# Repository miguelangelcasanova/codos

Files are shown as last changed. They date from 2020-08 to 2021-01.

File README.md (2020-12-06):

# 💪CODOS💪

## Un sistema de bajo coste basado en ESP8266/ESP32 para la detección del CO<sub>2</sub> y otras variables ambientales para monitorizar la calidad del aire en el aula (o en otros lugares de trabajo)

*(Se trata de un proyecto en constante actualización y este documento está en constante redacción)*

*"Algunos científicos comentan que mejorar la ventilación y la calidad del aire es un método que las escuelas pueden usar para reducir el riesgo de transmisión del coronavirus.
Sin embargo, en una encuesta entre distritos escolares grandes del Norte de Texas, The Dallas Morning News encontró que las escuelas están lejos de alcanzar los parámetros de calidad del aire propuestos en junio por expertos en construcción.
Investigadores de la Universidad de Harvard recomendaron instalar filtros de aire de alta graduación, limpiadores de aire portátiles y fuentes de luz ultravioleta dentro de los conductos de aire para eliminar al virus.
Al revisar el nivel de dióxido de carbono en las aulas se puede comprobar si está entrando suficiente aire fresco..."*

Fuente: https://noticiasenlafrontera.net/escuelas-no-siguen-recomendaciones-de-calidad-del-aire-parar-reducir-exposicion-a-covid-19/

Otro artículo con información al respecto, (gracias Lina por el enlace):

https://www.caloryfrio.com/construccion-sostenible/ventilacion-y-calidad-aire-interior/colegios-coronavirus-calidad-aire-interior-ventilacion-adecuada-covid-19.html

Existen además evidencias de que los altos niveles de CO<sub>2</sub> influyen sobre el rendimiento de los alumnos en el aula.
https://pubmed.ncbi.nlm.nih.gov/25117890/

Artículos cómo estos y otros me han llevado a elaborar un pequeño dispositivo de bajo coste que permita monitorizar los niveles de CO<sub>2</sub> en las aulas con el objeto de poder medir la concentración de dicho gas y de esta forma saber cuándo tenemos que renovar el aire de un aula para poder seguir de la mejor forma posible las propias indicaciones al respecto de las administraciones públicas españolas:

https://www.miteco.gob.es/es/ministerio/medidas-covid19/sistemas-climatizacion-ventilacion/default.aspx

Si quieres saber más no dejes de leer este interesantísimo hilo en twitter: https://twitter.com/PabloFuente/status/1297457593368088576

Utilizando una hoja de cálculo podemos calcular la cantidad de CO<sub>2</sub>  en función de diversas variables del aula. En el siguiente artículo tenemos una calculadora que permite hacer dicho cálculo, (gracias Mercedes por el enlace):

https://medium.com/@jjose_19945/how-to-quantify-the-ventilation-rate-of-an-indoor-space-using-a-cheap-co2-monitor-4d8b6d4dab44

Este enlace https://schools.forhealth.org/ventilation-guide/ nos dice también cómo y cuánto debemos ventilar...

En este reciente informe del 03/11/2020 nos hablan con datos de la importancia de la ventilación y de la necesidad de ventilar en las aulas más allá de lo que indican muchos de los protocolos vigentes en muchas comunidades autónomas:   *El muestreo de mediciones realizado en centros educativos por el Comité de Expertos en Ventilación del COGITI, confirma la necesidad de contar con medidores de CO2:* 
https://cogiti.es/el-muestreo-de-mediciones-realizado-en-centros-educativos-por-el-comite-de-expertos-en-ventilacion-del-cogiti-confirman-la-necesidad-de-contar-con-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

## ¿Qué es 💪CODOS💪?

💪CODOS💪 es un pequeño circuito electrónico construido sobre un microcontrolador ESP32, un microcontrolador similar a un Arduino pero que ofrece conectividad WiFi y Bluetooth, aunque también hay otros Arduinos como el MKR1000 WiFi que te podrían servir.

Esto significa que podemos usar dispositivos de [Internet de las Cosas, (IoT)](https://es.wikipedia.org/wiki/Internet_de_las_cosas) que nos permiten monitorizar los datos de los sensores conectados a los mismos a través de Internet.

CODOS está pensado para medir la cantidad de CO<sub>2</sub> y otros parámetros ambientales para recomendarnos cuando deberíamos renovar el aire de un aula u otro espacio de trabajo, sobre todo cuando no se disponga de un sistema de ventilación forzada, o bien no sea posible mantener las ventanas abiertas todo el tiempo.

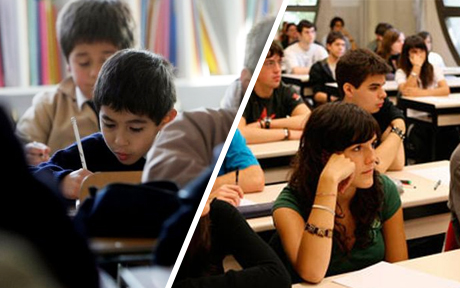
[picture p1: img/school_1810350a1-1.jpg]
CODOS es un guiño a hincar los codos en el aula...


Pupils at Henrietta Barnett School in Hampstead Garden Suburb raise their arms during a Key Stage Three maths lesson, the school received high scores during their Key Stage Three results, Wednesday 27 February, 2008. Photo: Jane Mingay

*CODOS (aka CO<sub>2</sub>) es un guiño a hincar los "CO<sub>2</sub>" en el aula... ;)*

* Con un simple Arduino, un sensor de CO<sub>2</sub> y unos led podemos construir un sistema simplificado que permita indicar cuando los niveles de CO<sub>2</sub> están dentro de unos determinado umbrales, esa fue mi primera idea y publicaré también esta versión; pero cambiando el Arduino por un ESP8266 o un ESP32 podemos además enviar los datos a un servidor y monitorizar por ejemplo los datos de distintas aulas de forma centralizada, almacenar datos estadísticos en una base de datos o realizar otras muchas tareas que podrían sernos útiles sin incrementar prácticamente el coste del dispositivo.

### BOM (Bill of materials) / Lista de materiales
En su versión IoT, para construir CODOS se necesitan los siguientes elementos:
- Un ESP32 por ejemplo el ESP32-DOIT-DEVKIT (también puedes utilizar un ESP8266)

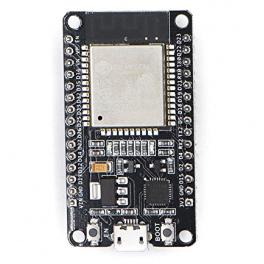
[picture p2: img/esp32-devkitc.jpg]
ESP32-DEVKITC


- Un sensor de CO<sub>2</sub>, como el MH-Z19b. Su gran ventaja es que se trata de un sensor NDIR por lo que mide directamente CO<sub>2</sub>.  (he probado también con otros sensores como el Sensirion SDC30 pero su coste es mucho más elevado). 

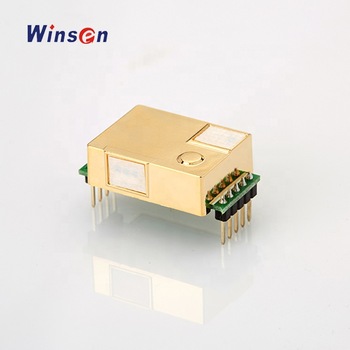
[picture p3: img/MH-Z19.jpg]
Sensor CO2 MH-Z19

 
- Otra alternativa más barata es el sensor de eCO<sub>2</sub> CCS811. Este sensor no mide directamente CO<sub>2</sub>, sino una estimación a partir de la presencia de otros gases. Aunque es útil para medir calidad del aire, no es el sensor más adecuado para este proyecto ya que puede dar niveles muy altos por otros motivos, y no solamente por acumulación de CO<sub>2</sub>.

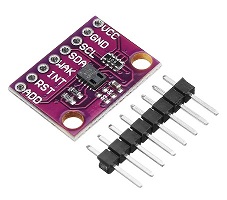
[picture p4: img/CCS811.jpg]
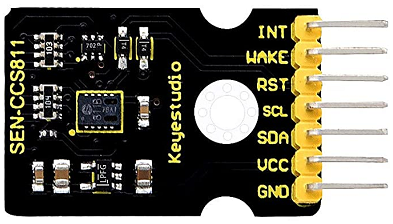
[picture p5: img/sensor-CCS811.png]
Sensor CO2 CCS811
 

- Opcionalmente un sensor de humedad, presión y temperatura BME280

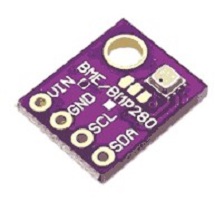
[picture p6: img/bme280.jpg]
Sensor BME280


- Opcionalmente leds de varios colores por ejemplo rojo, naranja y verde para construir un "semáforo" que indique los niveles de CO<sub>2</sub> o directamente utilizar un módulo de semáfot

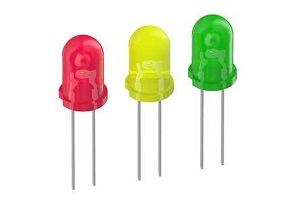
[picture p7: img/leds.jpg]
Diodos led
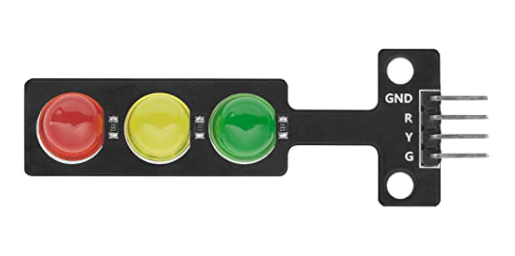
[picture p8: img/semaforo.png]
Semáforo de diodos LED
 

- Opcionalmente una pantalla OLED SSD1306 u otra (o un ESP32 que la incluya)

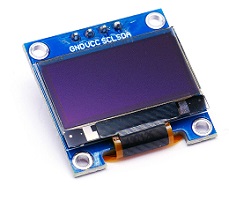
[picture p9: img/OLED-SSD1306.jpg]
OLED SSD1306


- Necesitarás además cables dupont para conectar entre sí los distintos elementos.

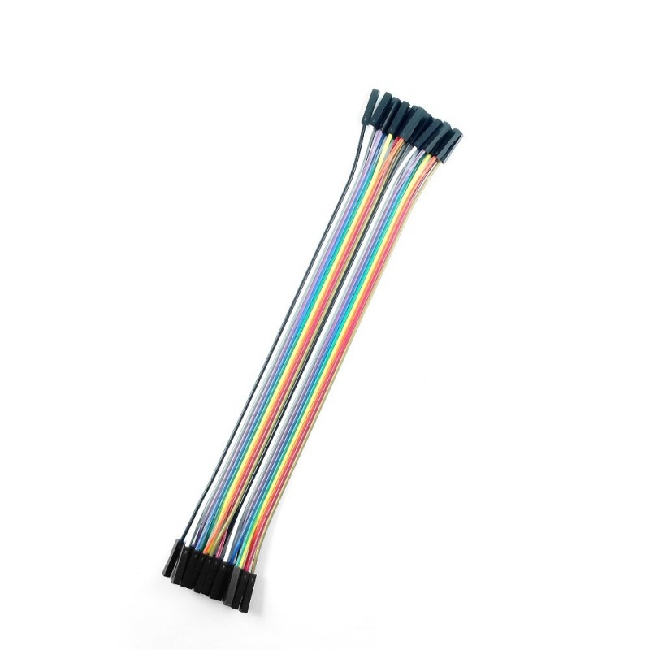
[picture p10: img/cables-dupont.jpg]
Cables Dupont


- Para alimentar el dispositivo podrás utilizar el puerto USB de un ordenador o mejor un cargador de móvil con conexión microUSB para los ESP o el que corresponga para el Arduino

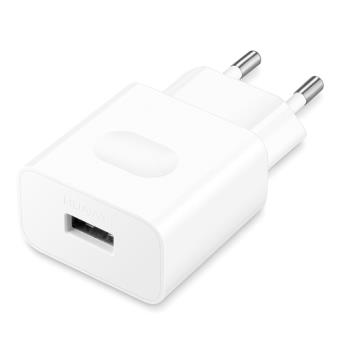
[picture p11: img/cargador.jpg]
Cargador de móvil
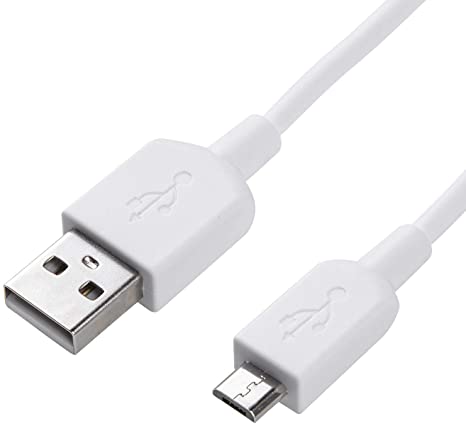
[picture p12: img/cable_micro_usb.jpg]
Cable Micro-USB


## Montaje

### Versión Arduino

Vamos a exponer primero de forma sencilla cómo se conecta el sensor de CO<sub>2</sub> CCS811 a un Arduino Nano o UNO, esta versión es la más económica y sencilla del dispositivo. Simplemente hemos de utilizar 5 cables Dupont hembra-hembra o macho-hembra respectivamente y unir los siguientes pines del sensor a otros tantos pines del Arduino:

- **Vcc** con un cable rojo lo uniremos al pin de 3.3V del Arduino
- **GND** con un cable negro lo uniremos a uno de los pines GND del Arduino
- **SDA** se conecta al pin A4 del Arduino
- **SCL** se conecta al pin A5 del Arduino
- **Wake** o **AWake** se conecta al otro pin GND del Arduino, aunque también podría controlarse con pin de salida.

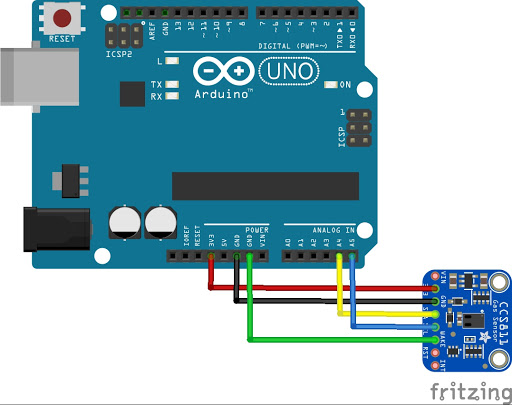
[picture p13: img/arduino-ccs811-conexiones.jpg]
Conexión del sensor CCS811 al Arduino


*Conexión del sensor CCS811 a un Arduino UNO*

Luego simplemente hemos de conectar un cable USB y podremos programar el Arduino con el código necesario para poder leer los datos del sensor.

Puedes utilizar el código de la carpeta dev/plotter para monitorizar los valores del CO<sub>2</sub> y la TVOC gráficamente. Puedes acceder al mismo en el siguiente enlace: https://github.com/miguelangelcasanova/codos/blob/master/dev/arduino/plotter/plotter.ino

El código está completamente comentado por lo que si lo deseas no debería resultarte muy dificil poder adaptarlo a tus necesidades.

En esta versión del dispositivo los datos sólo pueden monitorizarse a través de un ordenador conectado mediante dicho cable USB, por eso en la versión definitiva utilizaremos un ESP8266 o un ESP32 que funcionan de forma similar pero permiten además enviar los datos vía WiFi y en el caso del ESP32 también vía Bluetooth.

Descarga el archivo, envía el firmware al Arduino y abre el monitor serie o mejor el plotter serie y podrás visualizar los valores del sensor:

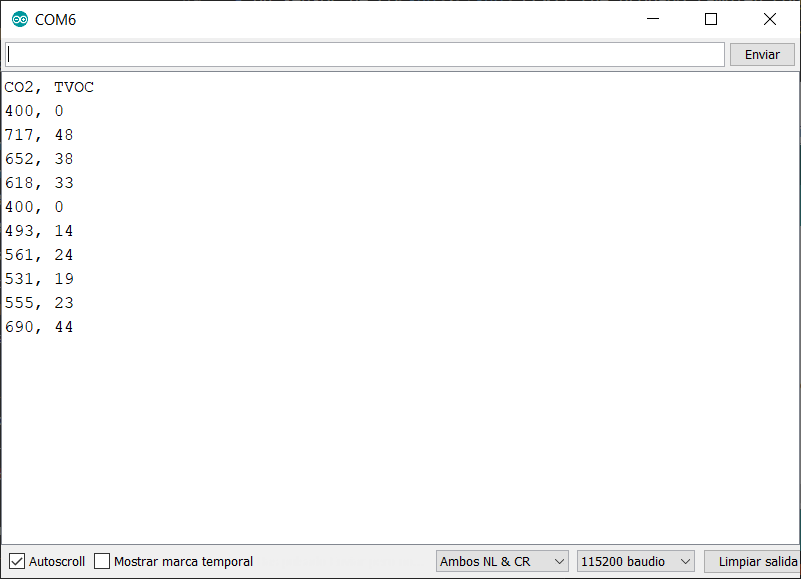
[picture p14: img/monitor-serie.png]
Monitor serie del IDE de Arduino con los valores medidos del sensor


*Monitor serie del IDE de Arduino*

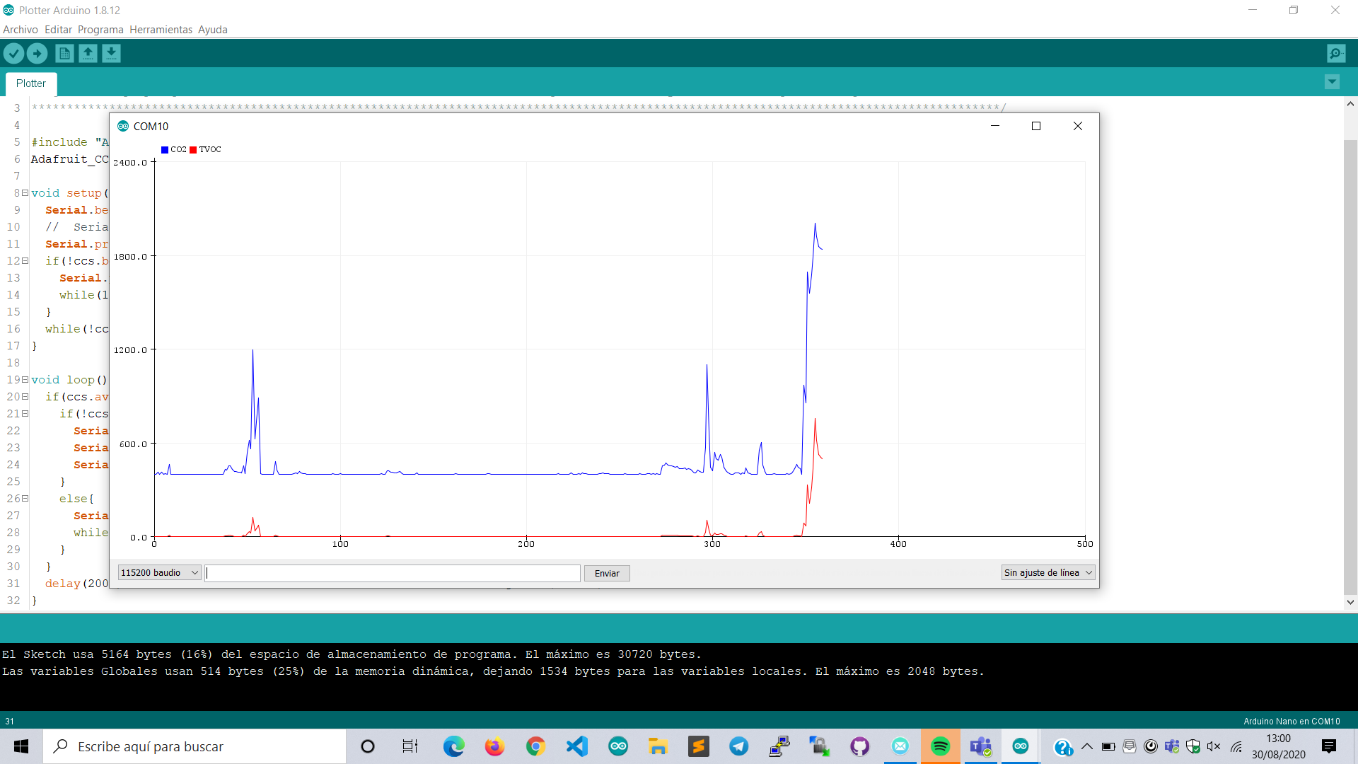
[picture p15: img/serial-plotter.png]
Serial Plotter del IDE de Arduino con los valores medidos del sensor


*Serial Plotter del IDE de Arduino*

### Version ESP8266 / ESP32

La conexión de los sensores es muy similar a la que hemos descrito para el arduino y es también muy sencilla, tanto el sensor de CO<sub>2</sub> como el sensor ambiental utilizados utilizan conexiones i2c, es decir basta con alimentarlos a 3.3V y masa. Luego hay que conectar a los **GPIO22** y **GPIO21** que en el ESP32 corresponden a las conexiones SCL y SDA del mencionado protocolo respectivamente o a los pines **D2** y **D1** que corresponden igualmente a SDA y SCL para el ESP8266.

Si deseas conectar la pantalla OLED o el sensor ambiental BME280, se conectan también en estos mismos pines en ambos casos.

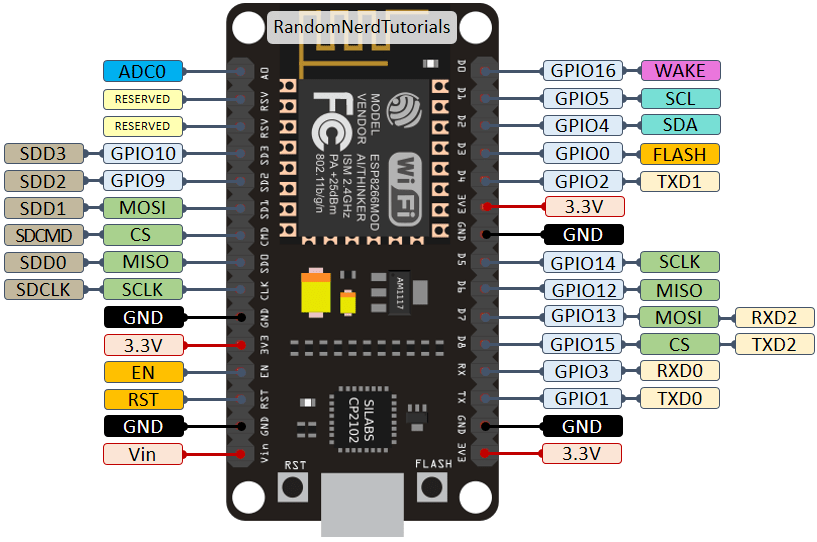
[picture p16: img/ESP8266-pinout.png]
Pinout del ESP8266

*Pinout del ESP8266*

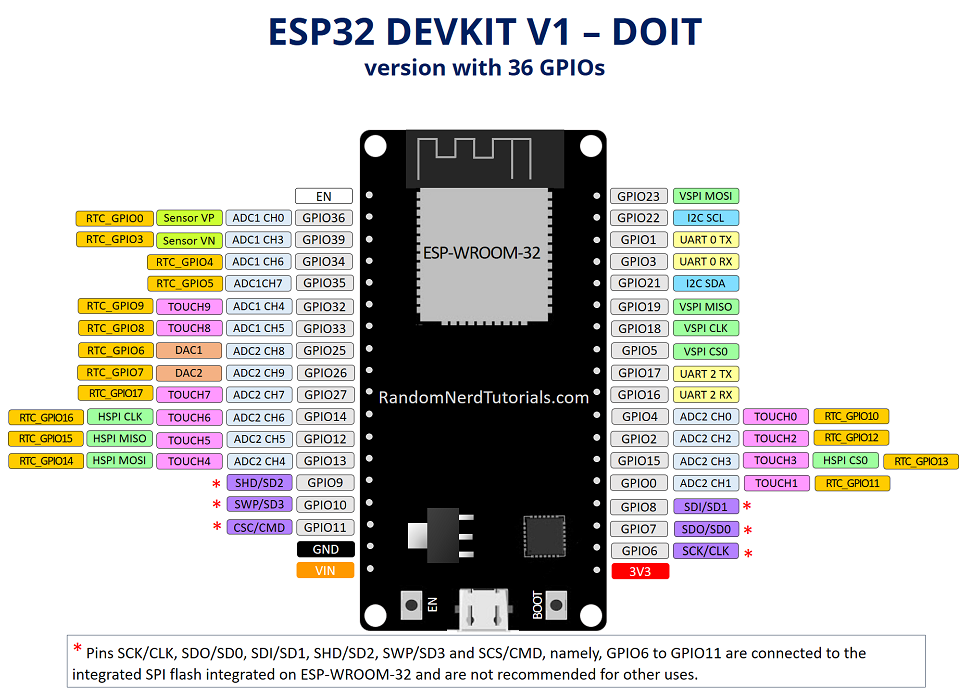
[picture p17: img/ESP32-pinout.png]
Pinout del ESP32

*Pinout del ESP32*

Dado que podemos utilizar dos pines para conectar varios sensores o la pantalla necesitaremos utilizar una placa de prototipos o diseñar una placa de circuito impreso para conectarlos todos en el mismo punto.

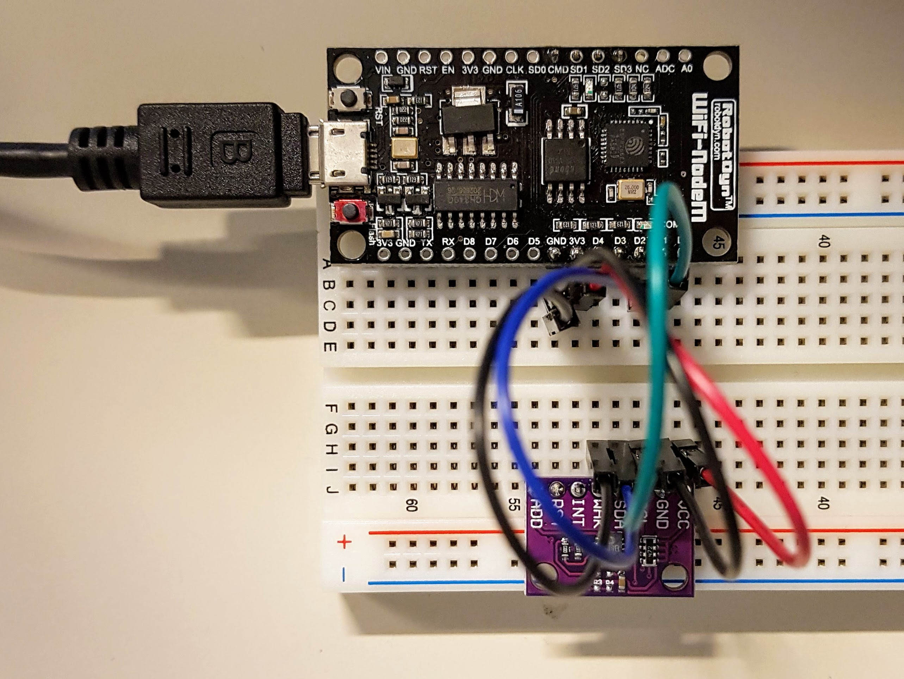
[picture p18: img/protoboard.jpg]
Conexión del sensor CCS811 con una placa protoboard
 *Conexión del sensor CCS811 a un ESP con una placa protoboard*

Para la conexión de los diodos led al tratarse de salidas de 3.3V deberíamos utilizar resistencias limitadoras de corriente y conectarlos a través de estas a cualquiera de los GPIO, yo he escogido los GPIO9, 10 y 11. Al conectar los diodos led hemos de tener en cuenta su polaridad.

### Otras versiones
Gracias a otros miembros de la comunidad el proyecto ha ido creciendo y enriqueciéndose con las contribuciones de makers, makerspaces y fablabs.

En la carpeta esp32 hay a tu disposición una versión avanzada que incluye el uso de bases de datos como InfluxDB para almacenar y visualizar en el futuro los datos de muchos sensores creada por Andreas del Makespace Mallorca.

### El programa
También he diseñado varias versiones del programa según la plataforma utilizada.
El programa debe cargarse desde el entorno IDE de Arduino o desde VS Studio Code (Platformio) en la placa correspondiente.

### El dispositivo
He diseñado una caja imprimible en 3D para poder albergar el dispositivo aunque este puede montarse directamente sobre una placa de prototipos si no se tiene la habilidad para soldar unos cuantos componentes aunque su montaje debería resultar especialmente sencillo.

En la carpeta STL hay diseños de cajas imprimibles en 3D y en Thingiverse puedes encontrar también otros modelos.

### Usando el dispositivo
El dispositivo se conecta automáticamente a la red del aula para permitir que los datos de los sensores pueden visualizarse en una página web que genera el dispositivo desde cualquier otro dispositivo conectado a la misma red. Para ello debes averiguar la dirección IP del dispositivo y abrir en tu navegador una URL del tipo siguiente: http://192.168.1.105 dónde los números indican la dirección IP local del dispositivo en la red local.

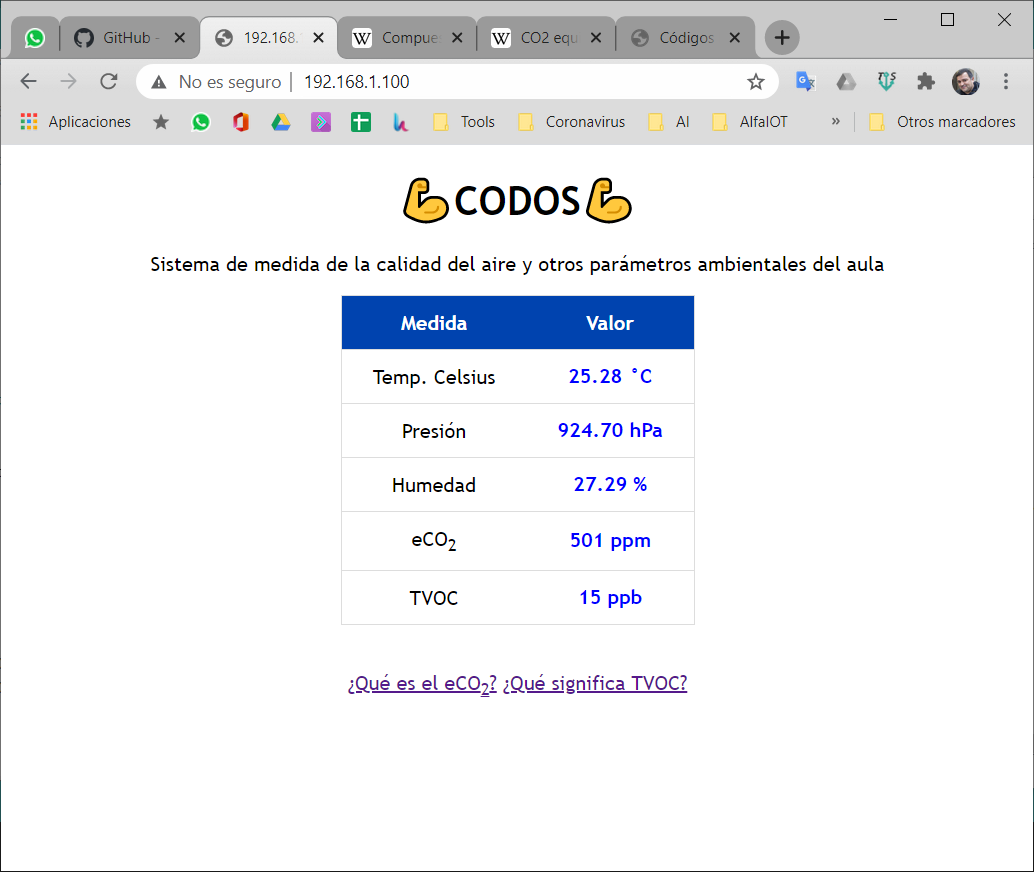
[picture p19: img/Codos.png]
CODOS


*Pantalla de datos de las primeras versiones de CODOS*

### Información para el calibrado de los sensores
Documentación para estudiar el comportamiento de los sensores en aire bajo condiciones controladas mediante materiales caseros.
[PROCEDIMIENTO](/doc/C%C3%A1lculos%20de%20concentraci%C3%B3n%20de%20CO2.pdf)

### To do
En un proyecto como este hay muchas cosas que siempre quedan por hacer. Por ejemplo, la calibración de los sensores es fundamental y no está bien probada, también es necesario hacer pruebas de campo montando sensores en las aulas y tomando medidas para comprobar su fiabilidad.
Si quieres colaborar no tienes más que ponerte en contacto con el grupo de trabajo por Telegram: https://t.me/codos_ventilacion (a 31 de octubre en el grupo hay 150 personas).

### Preguntas frecuentes

#### ¿Cuál es el objetivo del proyecto?
Dotar a las aulas y otros espacios de trabajo de una forma sencilla y económica
de medir la calidad del aire, en concreto de la concentración de CO<sub>2</sub>

#### ¿Dónde comprar los componentes?

El ESP32 y los leds se pueden comprar en muchas tiendas físicas de electrónica en España o a través de Internet. En China por supuesto resultan mucho más económico; pero tardarás en tenerlo varias semanas en tener los componentes en tus manos.
Los sensores son un poco más difíciles de localizar en tiendas físicas pero puedes adquirirlos igualmente en China o un poco más caros encontrarlos a través de ebay o Amazon.

El ESP32 lo puedes comprar en España por unos 10€ por ejemplo en:

https://www.ebay.es/itm/EL0116-ESP-WROOM-32-ESPRESSIF-Placa-Desarrollo-Arduino-WiFi-Bluetooth-Dual-Core/233565682462

En la misma tienda puedes comprar los LEDs y unos cables Dupont hembra-hembra.

En ebay y en Amazon hay muchas tiendas que te ofrecen el sensor de CO2 o el de humedad y temperatura pero su coste es mucho más elevado que pidiéndolo a China:

https://www.ebay.es/itm/CCS811-Carbon-Monoxide-CO-VOCs-Air-Quality-Numerical-Gas-Sensors-CJMCU-811/323688562130

https://www.amazon.es/TECNOIOT-Monoxide-Quality-Numerical-CJMCU-811/dp/B07RGLMS1J

Este es otro modelo que resulta también muy económico:

https://www.amazon.es/KEYESTUDIO-Quality-Arduino-Monoxide-Numeric/dp/B086HCSM6N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

Comprando 5 unidades del ESP32 te salen a 6€ en el siguiente enlace:

https://www.amazon.es/gp/product/B074RG86SR

En Aliexpress últimamente están entregando en 10 días (Hoy es 29/08/2020)

https://es.aliexpress.com/item/32903358923.html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,searchweb201602_,searchweb201603_

El MH-Z19b lo puedes adquirir también en Amazon o Aliexpress por unos 16-25€:
https://es.aliexpress.com/item/32946106807.html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

#### Otros proyectos parecidos

- *Air quality sensor:* This simple, fancy looking, ESP8266 based sensor measures values of CO2 and TVOC air pollutants. As output there is addressable RGB led strip, and/or optional OLED display which can show real time levels. https://github.com/Luc3as/Air-quality-Sensor/ (en inglés)

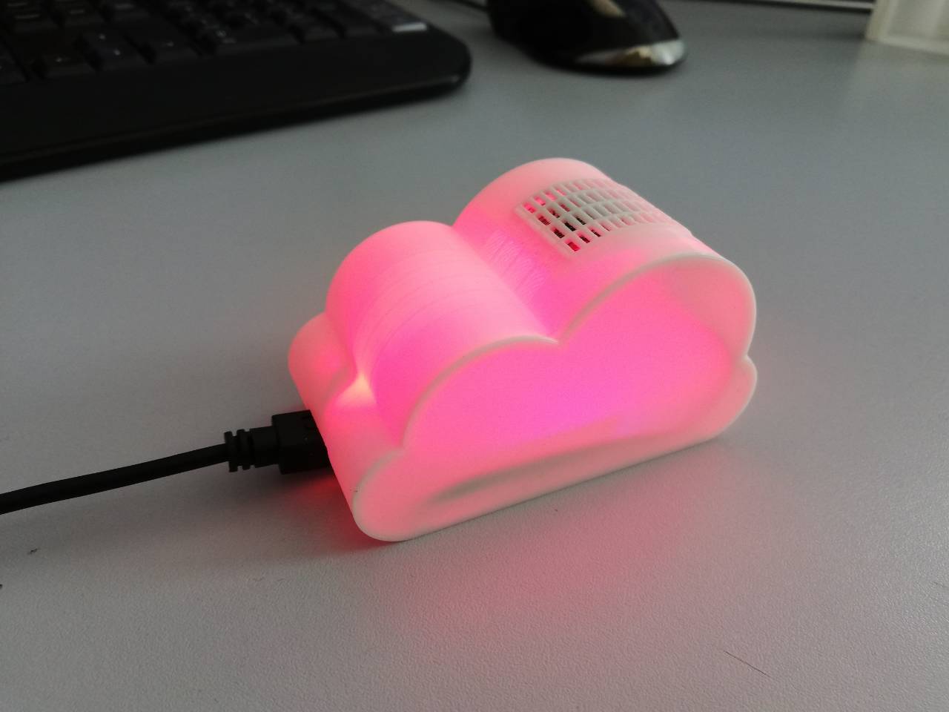
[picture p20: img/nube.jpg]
   
   
- *CO2 Cuckoo Clock for schools and businesses (Why not eCO2?)* del maker y youtuber suizo Andreas Spiess:  https://www.youtube.com/watch?v=hcPdZlpaRTo (en inglés)
  
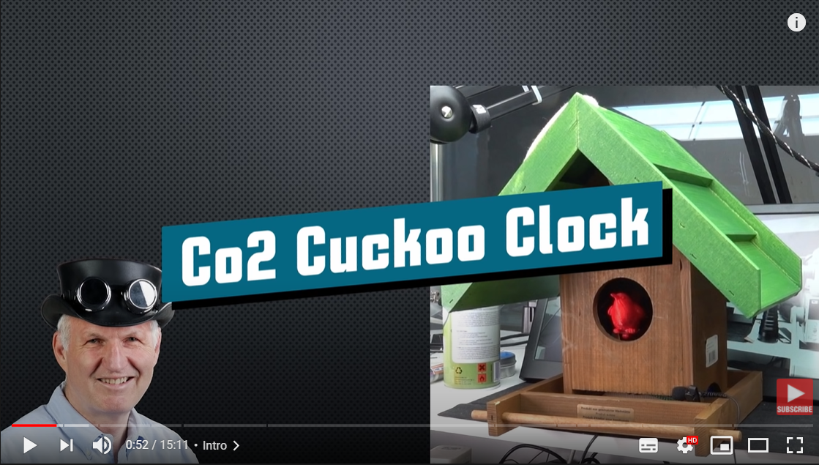
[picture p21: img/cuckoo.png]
  
  
- *Air quality meter:* http://www.futurashop.it/breakout-CCS811-air-quality-ft1331m-qualit%C3%A0%20aria?search=ccs811 (en italiano) 
  La caja puedes descargarla d*Air quality meter* (de David Daghetta, en Thingiverse): https://www.thingiverse.com/thing:2569792 (en Inglés)

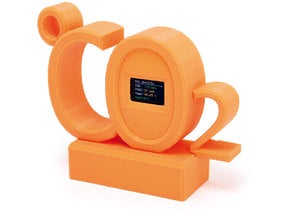
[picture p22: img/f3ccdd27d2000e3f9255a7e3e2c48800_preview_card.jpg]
CO2


*(Este documento está en constante redacción)*

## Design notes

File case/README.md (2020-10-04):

# 3D printable housings for CODOS air quality sensor based on ESP32/8266s & Arduinos
Housings with lot of space to hold several sensors and due to an interchangable base adaptable to all kinds of development board form factors. 
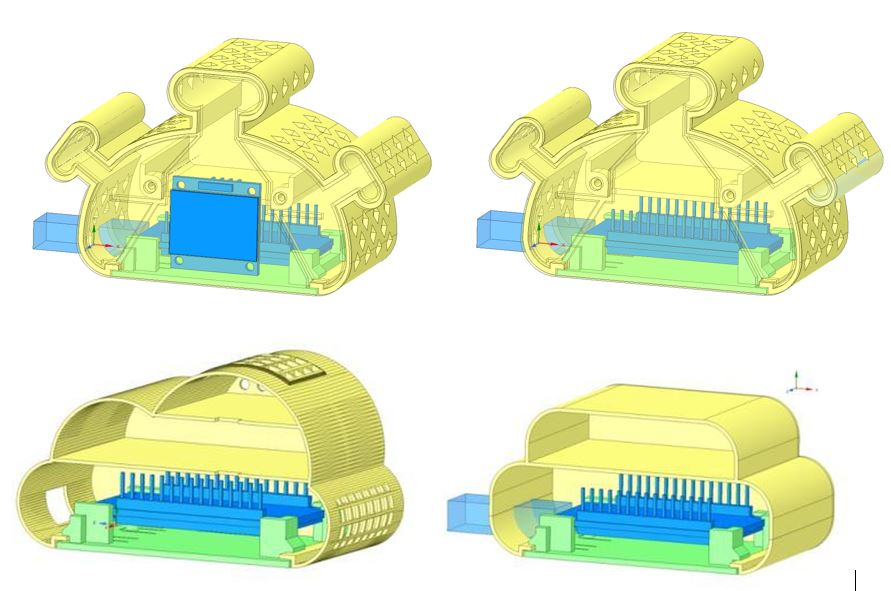
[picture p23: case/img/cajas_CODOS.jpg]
Screenshots housings


## Variety of holding bases:
* ESP32 30 pin, 51,5 x 28,5 mm
* ESP32 38 pin, 58 x 28 mm
* ESP8266 30 pin (NodeMCU), 58 x 31,2 mm
* ESP32-CAM, 40 x 27 mm
* TTGO T1 38 pin, 53,8 x 26,9 mm
* NANO 30 pin, 43,7 x 18 mm
* Wemos D1 mini, 34,2 x 25,4 mm - credits to Luc3as https://github.com/Luc3as/Air-quality-Sensor - based his design on https://www.thingiverse.com/thing:2997734
* UNO, 68,8 x 53 mm - Attention: needs housing "bicho_100_para_UNO"

## Different shapes
* "Virus" shaped
* "Cloud" shaped - credits to Luc3as https://github.com/Luc3as/Air-quality-Sensor - based on his design on https://www.thingiverse.com/thing:2997734 
* to come: Rectangular with rounded corners

## Versions
* v0.7 added case & base for UNO, reduced wall thickness
* v0.6 correction "bicho", base Wemos D1 mini added, "cloud" added
* v0.5 correction base TTGO T1, added premarked holes for LEDs
* v0.4 added version for 0.96" OLED + two more bases (TTGO T1 + NANO)
* v0.3 added side holes on top tentacle for better breathing of MH-Z19P sensor
* v0.2 initial release

# License
<br /><span xmlns:dct="http://purl.org/dc/terms/" href="http://purl.org/dc/dcmitype/Text" property="dct:title" rel="dct:type">CODOS case "bicho"</span> by <span xmlns:cc="http://creativecommons.org/ns#" property="cc:attributionName">@Andreas_IBZ (Telegram)</span> is licensed under a <a rel="license" href="http://creativecommons.org/licenses/by-nc-sa/4.0/">Creative Commons Attribution-NonCommercial-ShareAlike 4.0 International License</a>.

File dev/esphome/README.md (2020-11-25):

# Distintos sketches para ESPHome.

### nodemcu_ccs811.yaml

Archivo simple, para nodemcu y un sensor ccs811. 
Es necesario editarlo para configurar las credenciales de WiFi y la dirección del servidor MQTT

### esp32_mhz19_display.yaml

Plantilla para ESP32 con sensor MH-Z19 y display oled. Este archivo depende de otros incluidos en ./co2_common.
Es fácil modificar el tipo de sensor utilizado simplemente comentando/descomentando las líneas correspondientes:

    packages:
      display: !include "co2_common/display.yaml"
      mqtt: !include co2_common/mqtt.yaml 
      mhz19: !include "co2_common/sensor_mhz19.yaml"
      bme280: !include "co2_common/sensor_bme280.yaml"
      #  mq135: !include "co2_common/sensor_mq135.yaml"
      #  ccs811: !include "co2_common/sensor_ccs811.yaml"
 
Es necesario crear un archivo co2_common/secrets.yaml con las credenciales de wifi y otros parámetros. En esa carpeta se encuentra un archivo secrets.yaml.sample de ejemplo.

### wemosD1_ccs811_display.yaml
Mismo sistema de plantilla que el anterior, pero configurado para una placa WemosD1 y sensor CCS811

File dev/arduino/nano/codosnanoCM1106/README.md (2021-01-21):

# Arduino NANO + Display Oled + Sensor CM1106

Versión del proyecto codosnanoMHZ19, adaptada al sensor CM1106.

Soporta display OLED I2C conectado a A4 y A5

Semáforo de LEDS indicadores del estado de "alarma" (rojo, amarillo, verde), conectados a los pines 6, 7 y 8.

Se puede conectar un interruptor entre los pines 3 y GND. Al pulsarlo durante más de 2 segundos se calibra el sensor manualmente a 415ppm. (Esto debe hacerse al aire libre o en la ventana, después de tener el sensor funcionando varios minutos)

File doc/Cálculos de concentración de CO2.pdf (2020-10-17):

Determinación de ppm de CO2 en una garrafa de 5 litros de agua con aire limpio.

En el siguiente procedimiento se pretende obtener información sobre el calibrado de los sensores de concentración de CO2 en el aire para el proyecto CODOS, que busca monitorizar la concentración de CO2 en las aulas, como medida de la calidad del aire y optimizar la ventilación en la lucha contra el SARS-CoV-2.

https://github.com/miguelangelcasanova/codos

Pretendemos comparar del valor obtenido por el sensor y el valor teórico en aire bajo condiciones controladas.

A través de una reacción química buscamos modificar el valor de la concentración de CO2 en el aire contenido en la garrafa para conocer la respuesta de los diferentes sensores.

El aire de la garrafa debe ser obtenido en el exterior y alejado de fuentes de contaminación para considerar que partimos de una concentración de 400ppm de CO2.

La reacción tendrá lugar con la garrafa completamente cerrada.

Materiales:
- Una garrafa de agua (vacía) de 5 litros
- Bicarbonato sódico
- Vinagre
- Una jeringuilla que nos permita medir 1ml.

Consideraciones
- 1 mol de aire en CN ocupa 22,4 l
- Capacidad de la garrafa 5,1 l
- Proporción de ácido acético en el vinagre común 4%
- Reactivo limitante: Ácido acético, ya que es más fácil calcular su volumen
- Densidad del vinagre 1g/ml
- El contenido de CO2 en el aire limpio es de 400 ppm → 0,04%

Reacción química
NaHCO3 + CH3COOH => NaC2H3 O2 + H2O + CO2

Cada molécula de ácido acético produce una molécula de CO2.

Masa molecular (CH3COOH) = 60g/mol

Masa molecular (CO2) = 44g/mol

Masa molecular (NaHCO3) = 84g/mol

Aire de la garrafa inicial

1 mol ≈ 22,4 l por lo que tendremos aprox. 0,2277 moles ≈ 1,416·10²³ moléculas

Vinagre d≈1g/ml y → 1ml equivale a 1g de vinagre. En 1ml de vinagre tendremos 0,04g de CH3COOH

0,04g de CH3COOH son aprox. 4,015·10²⁰ moléculas

Después de la reacción
Nº total de moléculas en estado gaseoso = 1,416·1023 + 4,015·10²⁰ = 1,42 · 10²³ moléculas

Nº de moléculas de CO2 = 4,015·10²⁰ (obtenidas) + 4·10⁻⁴

- 1,416·10²³ = 4,5814 ·10²⁰ moléculas

Proporción
4,5664 ·10²⁰ / 1,42 · 10²³ ≈ 0,003226 ≈ 3226 ppm

Conclusión

Disolviendo completamente 1ml de vinagre en una cantidad suficiente de bicarbonato sódico (una cucharita pequeña) dentro de una garrafa llena de aire limpio (400 ppm de CO2) la concentración de CO2 ascenderá a 3226 ppm

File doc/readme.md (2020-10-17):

# Documentación

En esta carpeta hay diversos documentos útiles para el proyecto. Datasheet de diferentes sensores, guías de programación, información técnica y otra información de interés sobre el CO2.

A través del siguiente enlace se podrá tener acceso al documento en Google Docs de presentación del proyecto a centros educativos. Se encuentra abierto y es de libre edición.

[Documento Proyecto CODOS en Google Docs](https://docs.google.com/document/d/11AyAutbdyGciLlmV7_w-OJjZyPklUf59CmAjkQRwt4g)

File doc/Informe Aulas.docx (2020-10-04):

# Sistema de bajo coste basado en ESP8266/ESP32 para la detección del CO2 y otras variables ambientales para monitorizar la calidad del aire en el aula

"Algunos científicos comentan que mejorar la ventilación y la calidad del aire es un método que las escuelas pueden usar para reducir el riesgo de transmisión del coronavirus. Sin embargo, en una encuesta entre distritos escolares grandes del Norte de Texas, The Dallas Morning News encontró que las escuelas están lejos de alcanzar los parámetros de calidad del aire propuestos en junio por expertos en construcción.
Investigadores de la Universidad de Harvard recomendaron instalar filtros de aire de alta graduación, limpiadores de aire portátiles y fuentes de luz ultravioleta dentro de los conductos de aire para eliminar al virus. Al revisar el nivel de dióxido de carbono en las aulas se puede comprobar si está entrando suficiente aire fresco..."

Fuente: https://noticiasenlafrontera.net/escuelas-no-siguen-recomendaciones-de-calidad-del-aire-parar-reducir-exposicion-a-covid-19/

Miguel Ángel Casanova González, director del Centro Integrado de Formación Profesional Río Tormes de Salamanca, es el autor del proyecto CODOS que -en base a que diversos estudios e investigaciones prestigiosas, relacionan la cantidad de CO2 en las aulas con la capacidad de concentración del alumnado, así como de aumento de probabilidad de contagio de la COVID-19- pretende crear un dispositivo de bajo coste y con una precisión de medida suficientemente buena, como para poder detectar niveles nocivos de CO2 y por tanto, establecer cuándo se debe ventilar el aula.

Es obvio mencionar que hoy en día existe preocupación en el ámbito educativo debido a que las normas sanitarias recomiendan clases con pocos alumnos y siempre en entornos bien ventilados o exteriores. Estos escenarios no siempre se pueden conseguir en los centros educativos y crea la duda de cuándo se debe ventilar el aula. A finales del verano tal y como nos encontramos ahora, este no parece ser un riesgo inminente, ya que se pueden mantener las ventanas de las clases abiertas de forma permanente, pero en invierno y más en Salamanca de donde es Miguel Ángel, esto crea un serio problema. Es por ese motivo que Miguel Ángel decide ir un paso más allá, investigar cómo puede tratar el tema siempre usando el método científico y plantear una solución que sea posible técnicamente y viable a nivel económico.

Cabe decir que Miguel Ángel debido a su formación como físico, su inquietud por la innovación tecnológica y entusiasmo por compartir el conocimiento, ha creado el proyecto CODOS de forma abierta, lo que significa que cualquiera que quiera puede colaborar. Y es aquí en donde entra la comunidad maker de Mallorca con el Fablab Mallorca. Nos hemos puesto en contacto con él, hemos visto cuales son nuestras posibilidades para contribuir de nuevo con la sociedad a la hora de combatir contra la COVID-19 (ya lo hicimos hace unos meses creando 20.000 pantallas de acetato para nuestros enfermeros, médicos, etc…) y queremos ofrecer la posibilidad a cualquier escuela que lo crea útil, de montar dichos dispositivos a coste únicamente el de los materiales.

Para que las escuelas puedan tomar una decisión y conocer mejor en que consiste el proyecto CODOS, nos permitimos recoger la información que Miguel Ángel tiene colgada en su repositorio de Github (https://github.com/miguelangelcasanova/codos) y reproducirlo en este documento:

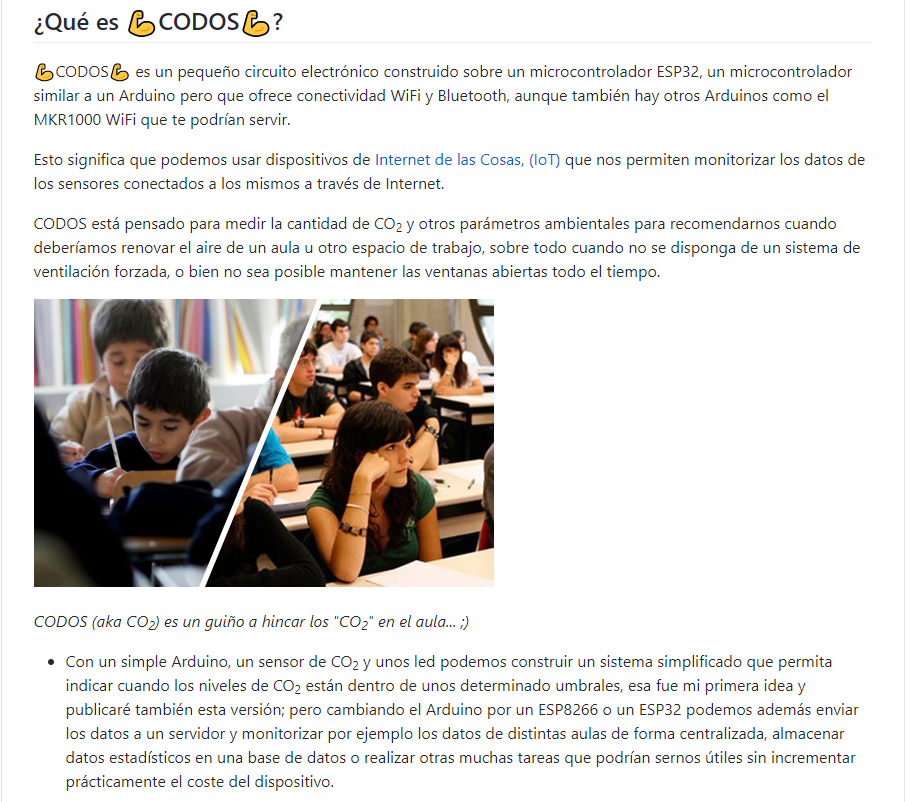
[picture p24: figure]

Fuente: https://github.com/miguelangelcasanova/codos

Sin entrar mucho en detalle, pero con el afán de procurar una visión global del dispositivo propuesto, se compone de un microcontrolador ESP32 con un sensor de CO2 CC811. Dicho sensor se encarga de medir cada cierto tiempo la cantidad de CO2 y la calidad del aire tVoc (Total Volatile Organic Compounds). Las principales características de este sensor son:

- Es capaz de medir el CO2 en un rango de 400ppm hasta 29206ppm
- Es capaz de medir el tVoC en un rango que va desde los 0ppb hasta 32768ppb
- Es capaz de medir la temperatura y humedad
- Funciona en un rango de temperaturas de -40ºC a 80ºC

Dicho dispositivo se encapsulará en una caja hecha mediante una impresora 3D que permitirá el flujo del aire correcto por el sensor y mostrará mediante los 3 leds (Rojo, Naranja y Verde) la calidad del aire medida.

Todos los detalles del proyecto, material, construcción y código, están accesible en el github de Miguel Ángel y de forma abierta a quien quiera usarlo para montarlo de forma autónoma. En nuestro caso, el Fablab Mallorca (http://fablabmallorca.com/), hemos decido ponerlo en marcha, crear varios dispositivos y presentarlos a las escuelas para que puedan ver su uso y efectividad.

Como ya hemos indicado anteriormente, el dispositivo cuenta con 3 leds a modo de semáforo que indica el nivel de concentración de CO2 en el aula, como también una web que publica el mismo dispositivo, accesible por wifi.

CODOS

Toda la información sobre el proyecto está disponible en el github (https://github.com/miguelangelcasanova/codos) y recomendamos su lectura, ya que es allí donde se publican las mejoras, cambios, preguntas, etc.

Finalmente, recomendamos también la lectura de los artículos que Miguel Ángel publica sobre los que basa su investigación y el porqué del proyecto.

Documento creado por Makespace Mallorca (https://makespacemallorca.org/) para la difusión del proyecto CODOS

Proyecto CODOS (https://github.com/Makespace-Mallorca/codos) en el github de Makespace Mallorca

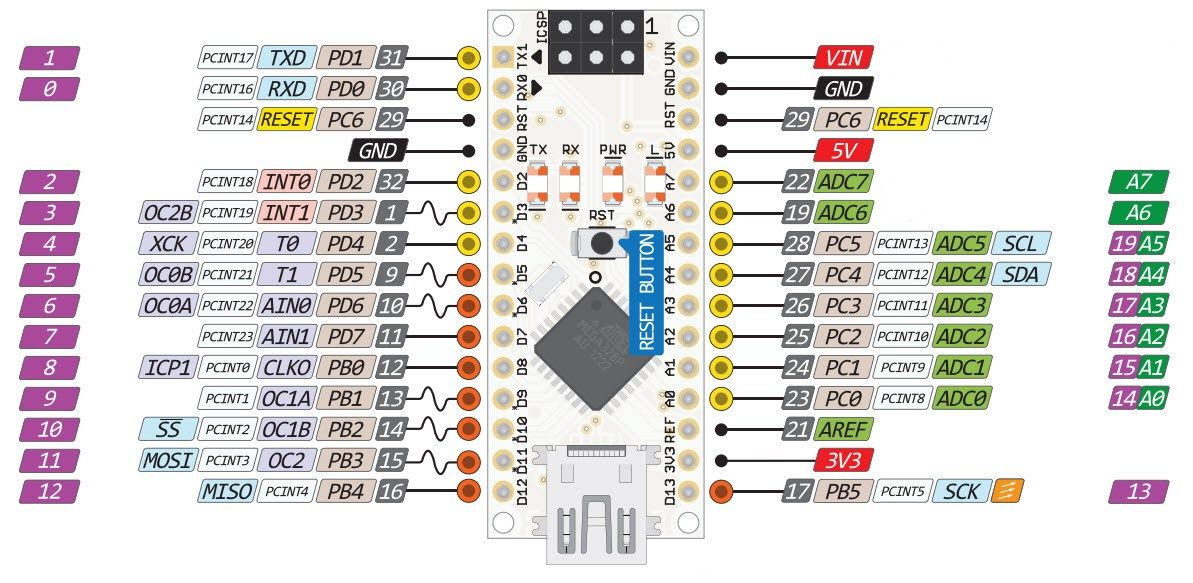
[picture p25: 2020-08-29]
img/arduino-nano-pinout.jpg

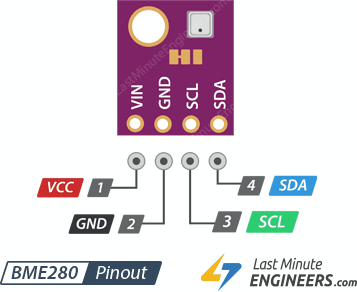
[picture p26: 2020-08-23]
img/BME280-Pinout-Temperature-Humidity-Barometric-Pressure-Sensor.png

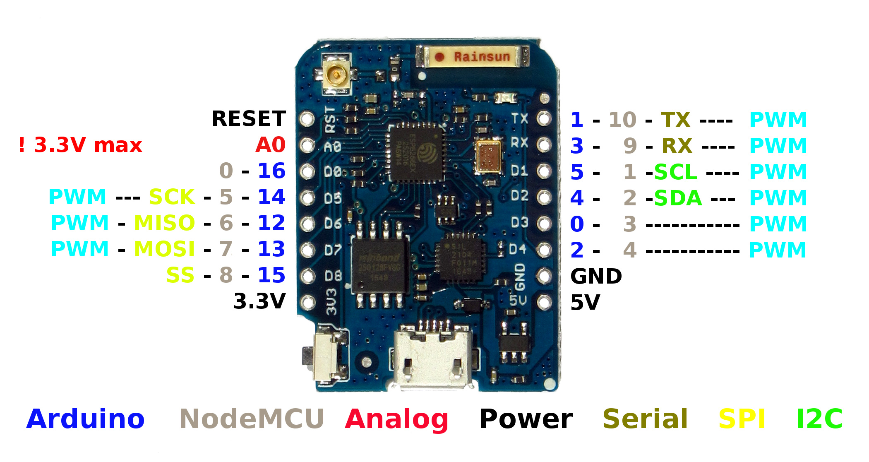
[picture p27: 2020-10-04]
dev/esp8266/codos_WeMos_D1_Mini_Pro/WEMOS D1 MINI Pro pinout.jpg

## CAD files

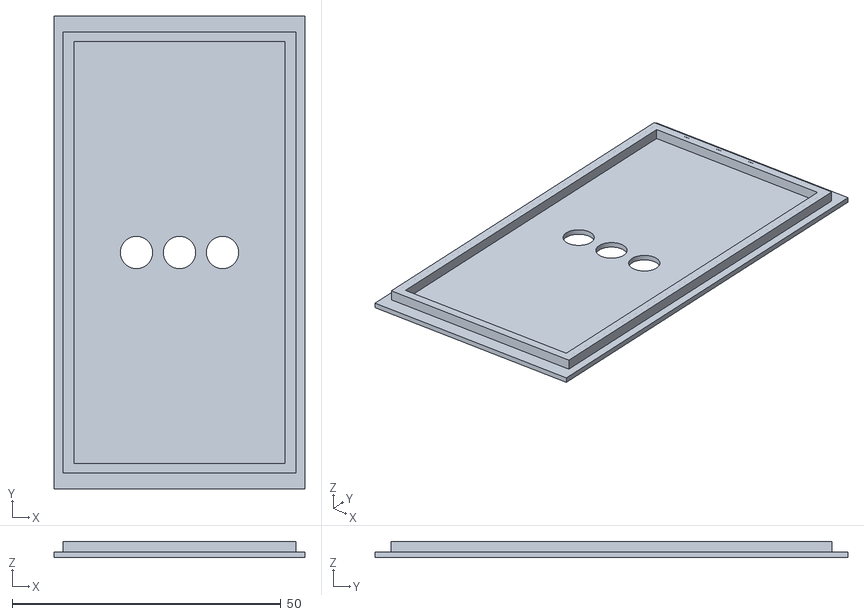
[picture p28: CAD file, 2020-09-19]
stl/caja/tapacajaCOdos.stl
46.7 x 87.9 x 3.00

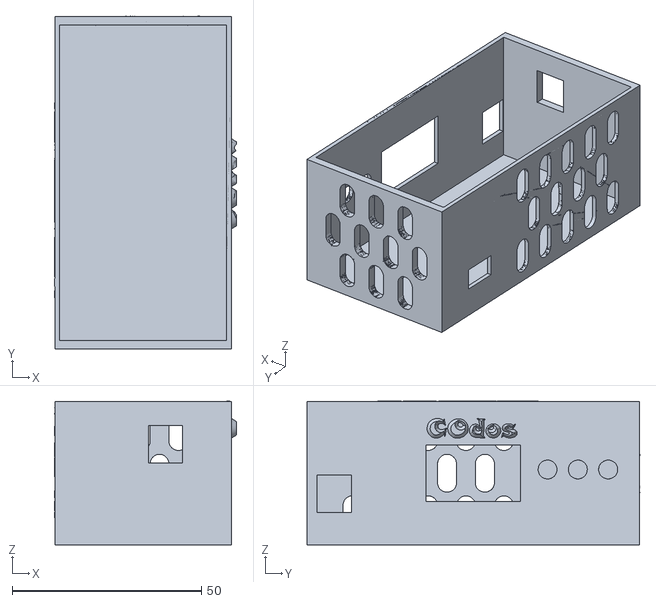
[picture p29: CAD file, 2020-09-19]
stl/caja/cajaco2_codos.stl
48.1 x 87.9 x 38.0

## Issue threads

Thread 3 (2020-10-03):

Cambio de detector de CO2

BySergy-Uny, 2020-10-03:
He encontrado este que es mucho mas barato haber si se podría integrar y es más fiable.

[enlace del detector de CO2](https://circuit.rocks/infrared-co2-sensor-analog-for-arduino-0-5000-ppm-gravity.html)

miguelangelcasanova, 2020-10-04:
Tiene muy buena pinta... claro que podría integrarse. Gracias por el enlace.

Closed 2020-10-04.

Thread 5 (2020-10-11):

Bosh BME680 vs CCS811 + BME280

ricardoper, 2020-10-11:
Buenos días,

Antes de nada, indicar que se trata de una buena idea para intentar de algún modo ayudar en estos momentos de dificultades.

Entiendo que la discusión de un o otro sensor es muy relativa y siempre hay pros y contras en todas las decisiones, pero creo que se podría optar por un sensor más completo por un precio igual o inferior en base a las características deseadas.

Para tener un eCO2 lo más fiable posible, añadir datos como temperatura y humedad sería lo más idóneo. Este tipo de compensaciones es muy importantes dependiendo de las estaciones y ciudades en que se pueda usar este dispositivo. Sé que tenéis como opcional el sensor BME280 de Bosch para estos casos pero a final el opcional siempre cae en el olvido.

Yo propongo el uso del sensor *[BME680](https://www.bosch-sensortec.com/products/environmental-sensors/gas-sensors-bme680/)* por las siguientes razones:
* Es prácticamente idéntico al sensor CCS811 pero cuenta con más datos ambientales (especialmente temperatura). Incluso con un coste prácticamente igual.
* El coste seria más bajo si sumamos los sensores CCS811 + BME280 manteniendo la funcionalidad de ambos. El opcional dejaría de tener sentido.
* El BME680 también se puede comprar en AliExpress en formato Breakout, [CJMCU-680](https://es.aliexpress.com/wholesale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).
* Si un día este proyecto cuaja y haya que realizar una PCB definitiva, este sensor ocupará muy poco espacio en comparación con el uso de dos sensores (CCS811 + BME280).
* El sensor CCS811 ya no esta recomendado para nuevos proyectos en vista que la compañía que los produce/desarrolla ha sido comprada y su futuro es incierto.

A nivel de librerías, no creo que sea un problema ya que tanto [Adafruit](https://github.com/adafruit/Adafruit_BME680) como la pagina de [Bosch](https://github.com/BoschSensortec/BME680_driver) las tienen disponibles.

Espero que esta información sea útil para el proyecto,
[Ricardo Pereira](https://ricardopereira.es/).

miguelangelcasanova, 2020-10-11:
Hola Ricardo, gracias por tu interés en el proyecto.
Te comento un poco el porqué de mis decisiones. Inicialmente plantee
únicamente el uso del CCS811 para medir el eCO2 y los TVOC. En realidad de
lo que se trataba era exactamente de eso.

La cuestión es que no es fácil para una escuela o instituto conseguir
presupuesto para montar decenas de sensores. por lo que el uso del
BME280 se puso como opcional.

Ciertamente el uso de senosres mejores como  el BME680 permite obtener
mejores resultados; pero el CCS811 no puedes sustituirlo por el BME680,
aunque sí el BME280.

En cualquier caso, los datos ambientales no resultan tan importantes para
la aplicación que se pretende y resulta mucho más fácil de localizar el
BME280 (o el BMP280) que el BME680, de forma local. De todas formas el uso
de uno u otro no cambia la funcionalidad del sistema.

La elección de la utilización del CCS811 no es más que una de las posibles
opciones. De lo que se trata es de que los usuarios sean conscientes de la
importancia de la ventilación de las aulas y espacios de trabajo.Si
prefieres utilizar otro sensor tampoco hay problema alguno. El kit de la
cuestión sigue siendo saber los valores que definen cuándo hay que ventilar
para un aula o espacio determinado en función del tamaño de la sala, el
número de personas... es ahí dónde debemos centrar los esfuerzos para
encontrar los mejores valores.

Un saludo, Miguel Ángel.

El dom., 11 oct. 2020 a las 11:15, Ricardo Pereira (<
notifications@github.com>) escribió:

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

ricardoper, 2020-10-11:
Hola Miguel Ángel,

Muchas gracias por la respuesta tan detallada y por ilustrar las ideas en que se basan este proyecto.

En base a tu respuesta, cerraré este Issue.

Un saludo,
Ricardo Pereira.

Closed 2020-10-11.

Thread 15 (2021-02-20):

Sugerencia relé

manolodd, 2021-02-20:
Buenas,

Buen trabajo! Como sugerencia se podría preparar el código para disparar un relé tomando como referencia dos valores (como ocurre con las bombas de extracción de agua). Por si en el aula se dispone de un extractor helicoidal para ayudar a ventilar. Así se podría encender automáticamente cuando se llega al tope y estar en funcionamiento hasta que se llegue al nivel "óptimo".

Un saludo.

miguelangelcasanova, 2021-02-23:
Por supuesto, es tan sencillo como poner en alto/bajo un pin cuando se llegue al valor prefijado, aunque para evitar problemas sería más interesante introducir unos valores de histéresis. Si te animas a hacer el código lo añadimos al repo y sino sabes proponlo por el grupo de Telegram y te ayudamos.

Closed 2021-02-23.

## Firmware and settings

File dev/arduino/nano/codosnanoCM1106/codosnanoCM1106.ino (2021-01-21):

/*********************************************************************************
CODOS AKA CO2 
Un sistema de bajo coste basado en Arduino NANO, OLED SS1306, CM1106 para la detección del CO2 
y temperatura en el aula
*********************************************************************************/

char VERSION_SW[6] = "v1.10";
#include "Wire.h"                       // Librería Wire para el soporte del protocolo i2c

#include <SoftwareSerial.h>                                // Remove if using HardwareSerial or Arduino package without SoftwareSerial support

#define RX_PIN 2                                          // Rx pin which the CM1106 Tx pin is attached to
#define TX_PIN 4                                          // Tx pin which the CM1106 Rx pin is attached to
#define BAUDRATE 9600                                     // Device to CM1106 Serial baudrate (should not be changed)
#define CALIBRATION_PIN 3                                 // Long press to force calibrate (Use a PIN that supports interrupts)

#define PREHEATING_TIME 30000                             // Por especificaciones tiene un PREHEATING Time de 30 segundos

#define CALIBRATION_VALUE 415                             // Clean air CO2ppm

const int CO2_safe_level = 800;        // Se debe especificar un valor máximo de CO2 seguro
const int CO2_alarm_level = 1200;       // Se debe especificar un valor máximo de CO2 de alarma


SoftwareSerial mySerial(RX_PIN, TX_PIN);                   // (Uno example) create device to CM1106 serial

#include <Adafruit_GFX.h>
#include <Adafruit_SSD1306.h>

#define CO2_sensor_present true         // Debe seleccionarse si este sensor está o no presente
#define OLED_present true              // Debe seleccionarse si la pantalla está o no presente
#define traffic_lights_present true     // Debe seleccionarse si se conectará el semáforo o no (el sensor de CO2 debe estar presente también en ese caso)

// Pines Digitales que he usado en el arduino NANO
#define verde 6
#define amarillo 7
#define rojo 8
#define BUILTIN_LED 13

#define SCREEN_WIDTH 128 // OLED display width, in pixels
#define SCREEN_HEIGHT 32 // OLED display height, in pixels

// Declaration for an SSD1306 display connected to I2C (SDA, SCL pins)
#define OLED_RESET     4 // Reset pin # (or -1 if sharing Arduino reset pin)
Adafruit_SSD1306 display(SCREEN_WIDTH, SCREEN_HEIGHT, &Wire, OLED_RESET);

// Imagenes generadas a partir de LCD Assistant (http://en.radzio.dxp.pl/bitmap_converter/)
// con iconos descargados de https://iconarchive.com/ 
const unsigned char PROGMEM happy_icon [] = {
0x00, 0x00, 0x00, 0xFF, 0xFF, 0x00, 0x00, 0x00, 0x00, 0x00, 0x3F, 0xF0, 0x0F, 0xFC, 0x00, 0x00,
0x00, 0x03, 0xF0, 0x00, 0x00, 0x0F, 0xC0, 0x00, 0x00, 0x0F, 0x00, 0x00, 0x00, 0x00, 0xF0, 0x00,
0x00, 0x3C, 0x00, 0x00, 0x00, 0x00, 0x3C, 0x00, 0x00, 0xF0, 0x00, 0x00, 0x00, 0x00, 0x0F, 0x00,
0x03, 0xC0, 0x00, 0x00, 0x00, 0x00, 0x03, 0xC0, 0x03, 0x00, 0x00, 0x00, 0x00, 0x00, 0x00, 0xC0,
0x0F, 0xFF, 0xFF, 0xFF, 0xFF, 0xFF, 0xFF, 0xF0, 0x3F, 0xF0, 0x03, 0xFC, 0x3C, 0x00, 0x0F, 0xFC,
0xF0, 0x00, 0x0F, 0x3C, 0x3C, 0x00, 0x00, 0xFF, 0xC0, 0x00, 0x0C, 0x3F, 0xFC, 0x00, 0x03, 0xC3,
0xC0, 0x00, 0x3C, 0x3C, 0x3C, 0x00, 0x03, 0x03, 0xC0, 0x00, 0x30, 0x30, 0x0C, 0x00, 0x0F, 0x03,
0xC0, 0x00, 0xF0, 0x30, 0x0C, 0x00, 0x0C, 0x03, 0xF0, 0x00, 0xC0, 0xF0, 0x0F, 0x00, 0x3C, 0x0F,
0xF0, 0x03, 0xC3, 0xC0, 0x03, 0xC0, 0x30, 0x0F, 0xFF, 0xFF, 0xFF, 0x00, 0x00, 0xFF, 0xFF, 0xFF,
0xF3, 0xFF, 0x00, 0x00, 0x00, 0x00, 0xFF, 0xCF, 0xF0, 0x00, 0x00, 0x00, 0x00, 0x00, 0x00, 0x0F,
0x30, 0x00, 0x00, 0x00, 0x00, 0x00, 0x00, 0x0C, 0x30, 0x00, 0x00, 0x00, 0x00, 0x00, 0x00, 0x0C,
0x3C, 0x00, 0x00, 0x00, 0x00, 0x00, 0x00, 0x3C, 0x0C, 0x03, 0x00, 0x00, 0x00, 0x00, 0xC0, 0x30,
0x0F, 0x00, 0xF0, 0x00, 0x00, 0x0F, 0x00, 0xF0, 0x03, 0xC0, 0x3C, 0x00, 0x00, 0x3C, 0x03, 0xC0,
0x00, 0xF0, 0x0F, 0xF0, 0x0F, 0xF0, 0x0F, 0x00, 0x00, 0x3C, 0x00, 0x3F, 0xFC, 0x00, 0x3C, 0x00,
0x00, 0x0F, 0x00, 0x00, 0x00, 0x00, 0xF0, 0x00, 0x00, 0x03, 0xF0, 0x00, 0x00, 0x0F, 0xC0, 0x00,
0x00, 0x00, 0x3F, 0xF0, 0x0F, 0xFC, 0x00, 0x00, 0x00, 0x00, 0x00, 0xFF, 0xFF, 0x00, 0x00, 0x00
};

const unsigned char PROGMEM Angry_icon [] = {
0x00, 0x00, 0x00, 0xFF, 0xFF, 0x00, 0x00, 0x00, 0x00, 0x00, 0x3F, 0xF0, 0x0F, 0xFC, 0x00, 0x00,
0x00, 0x03, 0xF0, 0x00, 0x00, 0x0F, 0xC0, 0x00, 0x00, 0x0F, 0x00, 0x00, 0x00, 0x00, 0xF0, 0x00,
0x00, 0x3C, 0x00, 0x00, 0x00, 0x00, 0x3C, 0x00, 0x00, 0xF3, 0xF0, 0x00, 0x00, 0x0F, 0xCF, 0x00,
0x03, 0xC0, 0x3F, 0x00, 0x00, 0xFC, 0x03, 0xC0, 0x0F, 0x00, 0x03, 0xF0, 0x0F, 0xC0, 0x00, 0xF0,
0x0C, 0x00, 0x00, 0x30, 0x0C, 0x00, 0x00, 0x30, 0x3C, 0x00, 0x3C, 0x00, 0x00, 0x3C, 0x00, 0x3C,
0x30, 0x00, 0xFF, 0x00, 0x00, 0xFF, 0x00, 0x0C, 0x30, 0x03, 0x00, 0xC0, 0x03, 0x00, 0xC0, 0x0C,
0xF0, 0x03, 0x00, 0xC0, 0x03, 0x00, 0xC0, 0x0F, 0xF0, 0x03, 0x00, 0xC0, 0x03, 0x00, 0xC0, 0x0F,
0xC0, 0x03, 0xC3, 0xC0, 0x03, 0xC3, 0xC0, 0x03, 0xC0, 0x00, 0xFF, 0x00, 0x00, 0xFF, 0x00, 0x03,
0xC0, 0x00, 0x00, 0x00, 0x00, 0x00, 0x00, 0x03, 0xC0, 0x00, 0x00, 0x00, 0x00, 0x00, 0x00, 0x03,
0xF0, 0x00, 0x00, 0x00, 0x00, 0x00, 0x00, 0x0F, 0xF0, 0x00, 0x00, 0x00, 0x00, 0x00, 0x00, 0x0F,
0x30, 0x00, 0x00, 0x3F, 0xFC, 0x00, 0x00, 0x0C, 0x30, 0x00, 0x0F, 0xF0, 0x0F, 0xF0, 0x00, 0x0C,
0x3C, 0x00, 0x3C, 0x00, 0x00, 0x3C, 0x00, 0x3C, 0x0C, 0x00, 0xF0, 0x00, 0x00, 0x0F, 0x00, 0x30,
0x0F, 0x03, 0x00, 0x00, 0x00, 0x00, 0xC0, 0xF0, 0x03, 0xC0, 0x00, 0x00, 0x00, 0x00, 0x03, 0xC0,
0x00, 0xF0, 0x00, 0x00, 0x00, 0x00, 0x0F, 0x00, 0x00, 0x3C, 0x00, 0x00, 0x00, 0x00, 0x3C, 0x00,
0x00, 0x0F, 0x00, 0x00, 0x00, 0x00, 0xF0, 0x00, 0x00, 0x03, 0xF0, 0x00, 0x00, 0x0F, 0xC0, 0x00,
0x00, 0x00, 0x3F, 0xF0, 0x0F, 0xFC, 0x00, 0x00, 0x00, 0x00, 0x00, 0xFF, 0xFF, 0x00, 0x00, 0x00
};

const unsigned char PROGMEM Surprised_icon [] = {
0x00, 0x00, 0x00, 0x03, 0xC0, 0x00, 0x00, 0x00, 0x00, 0x00, 0x0F, 0xFF, 0xFF, 0xF0, 0x00, 0x00,
0x00, 0x00, 0xFF, 0x00, 0x00, 0xFF, 0x00, 0x00, 0x00, 0x03, 0xC0, 0x00, 0x00, 0x03, 0xC0, 0x00,
0x00, 0x0F, 0x00, 0x00, 0x00, 0x00, 0xF0, 0x00, 0x00, 0x30, 0x3F, 0xF0, 0x0F, 0xF0, 0x3C, 0x00,
0x00, 0xC0, 0xF0, 0x30, 0x0C, 0x3F, 0x0F, 0x00, 0x03, 0xC0, 0xC0, 0x00, 0x00, 0x03, 0x03, 0xC0,
0x0F, 0x03, 0xC0, 0x00, 0x00, 0x03, 0xC0, 0xC0, 0x0C, 0x00, 0x0F, 0xC0, 0x03, 0xF0, 0x00, 0x30,
0x0C, 0x00, 0x0F, 0xC0, 0x03, 0xF0, 0x00, 0x30, 0x3C, 0x00, 0x0F, 0xC0, 0x03, 0xF0, 0x00, 0x3C,
0x30, 0x00, 0x0F, 0xC0, 0x03, 0xF0, 0x00, 0x0C, 0x30, 0x00, 0x03, 0x00, 0x00, 0xC0, 0x00, 0x0C,
0x30, 0x00, 0x00, 0x00, 0x00, 0x00, 0x00, 0x0C, 0x30, 0x00, 0x00, 0x00, 0x00, 0x00, 0x00, 0x0C,
0x30, 0x00, 0x00, 0x03, 0xC0, 0x00, 0x00, 0x0C, 0x30, 0x00, 0x00, 0x3F, 0xFC, 0x00, 0x00, 0x0C,
0x30, 0x00, 0x00, 0xF0, 0x0F, 0x00, 0x00, 0x0C, 0x30, 0x00, 0x03, 0xC0, 0x03, 0xC0, 0x00, 0x0C,
0x3C, 0x00, 0x03, 0x00, 0x00, 0xC0, 0x00, 0x3C, 0x0C, 0x00, 0x0F, 0x00, 0x00, 0xF0, 0x00, 0x30,
0x0F, 0x00, 0x03, 0xFF, 0xFF, 0xC0, 0x00, 0xF0, 0x03, 0x00, 0x00, 0x03, 0xC0, 0x00, 0x00, 0xC0,
0x03, 0xC0, 0x00, 0x00, 0x00, 0x00, 0x03, 0xC0, 0x00, 0xF0, 0x00, 0x00, 0x00, 0x00, 0x0F, 0x00,
0x00, 0x3C, 0x00, 0x00, 0x00, 0x00, 0x3C, 0x00, 0x00, 0x0F, 0x00, 0x00, 0x00, 0x00, 0xF0, 0x00,
0x00, 0x03, 0xF0, 0x00, 0x00, 0x0F, 0xC0, 0x00, 0x00, 0x00, 0x3F, 0xC0, 0x03, 0xFC, 0x00, 0x00,
0x00, 0x00, 0x03, 0xFF, 0xFF, 0xC0, 0x00, 0x00, 0x00, 0x00, 0x00, 0x00, 0x00, 0x00, 0x00, 0x00
};

const unsigned char PROGMEM Increibles_logo [] = {
0x00, 0x00, 0x00, 0x0F, 0x80, 0x00, 0x00, 0x00, 0x00, 0x00, 0x00, 0x7F, 0xF0, 0x00, 0x00, 0x00,
0x00, 0x00, 0x00, 0x7F, 0xFC, 0x00, 0x00, 0x00, 0x00, 0x00, 0x01, 0xF8, 0x3F, 0xC0, 0x00, 0x00,
0x00, 0x00, 0x7F, 0xF0, 0x1E, 0x1E, 0x00, 0x00, 0x00, 0x03, 0xFF, 0xC0, 0x1E, 0x00, 0xC0, 0x00,
0x00, 0x1F, 0xFF, 0xC0, 0x1E, 0x00, 0x38, 0x00, 0x00, 0x7F, 0xFF, 0xF0, 0x3E, 0x00, 0x0F, 0x00,
0x01, 0xFF, 0xFF, 0xF8, 0xFC, 0x00, 0x01, 0x80, 0x03, 0xFF, 0xF8, 0x7F, 0xF0, 0x00, 0x00, 0xC0,
0x0F, 0xFF, 0x80, 0x1F, 0xE0, 0x00, 0x00, 0xF0, 0x1F, 0xFC, 0x00, 0x00, 0x00, 0x00, 0x00, 0x78,
0x3F, 0xF8, 0x00, 0x00, 0x00, 0x00, 0x00, 0x7E, 0x3F, 0xC0, 0x00, 0x00, 0x00, 0x00, 0x00, 0x1E,
0x3F, 0x00, 0x00, 0x00, 0x1C, 0x00, 0x00, 0x1F, 0xFF, 0x00, 0x00, 0x03, 0xFC, 0x00, 0x00, 0x1F,
0xFE, 0x00, 0x00, 0x7F, 0xFC, 0x00, 0x00, 0x1F, 0xFE, 0x00, 0x00, 0x1F, 0xFC, 0x00, 0x00, 0x7F,
0xFC, 0x00, 0x00, 0x1F, 0xFC, 0x00, 0x00, 0x7F, 0xFC, 0x00, 0x00, 0x1F, 0xFC, 0x00, 0x00, 0xFF,
0x3C, 0x00, 0x00, 0x1F, 0xFC, 0x00, 0x00, 0xFE, 0x3C, 0x00, 0x00, 0x1F, 0xFC, 0x00, 0x01, 0xFE,
0x3E, 0x00, 0x00, 0x1F, 0xFC, 0x00, 0x0F, 0xFE, 0x1E, 0x00, 0x00, 0x1F, 0xFC, 0x00, 0x3F, 0xF8,
0x0F, 0x00, 0x00, 0x1F, 0xFC, 0x00, 0xFF, 0xF0, 0x03, 0xC0, 0x00, 0x1F, 0xFC, 0x3F, 0xFF, 0xC0,
0x01, 0xE0, 0x00, 0x1F, 0xFF, 0xFF, 0xFF, 0x80, 0x00, 0x78, 0x00, 0x1F, 0xFF, 0xFF, 0xFF, 0x00,
0x00, 0x1E, 0x00, 0x1F, 0xFF, 0xFF, 0xF8, 0x00, 0x00, 0x03, 0xC0, 0x1F, 0xFF, 0xFF, 0xC0, 0x00,
0x00, 0x00, 0x7C, 0x1F, 0xFF, 0xFE, 0x00, 0x00, 0x00, 0x00, 0x00, 0xFF, 0xFF, 0x00, 0x00, 0x00
};

unsigned long getDataTimer = 0;

const int OFFSET_CALIBRATION_TEMP = -6; // Valor obtenido de comparar con un termometro mas fiable que tengo en casa.. NO ES MUY FIABLE
const int OFFSET_CALIBRATION_PPM = 0; // Esta calibracion esta inventada (PENDIENTE) porque supongo que debiera ser unas tablas en funcion de temp y humedad asi que tomo un valor conservador para intentar no generar falsa alarma en el aula.
int p1 = 0; // Variable donde calculo el porcentaje sobre el limite establecido como ROJO
char leyend[15] = "12345678901234"; // Variable donde pongo la leyenda que se pinta en la barra de progreso en funcion del estado
char leyendGREEN[15] = "AULA OK"; 
char leyendRED[15] = "VENTILAR"; 
char leyendYELLOW[15] = "LIMITE KO"; 
char leyendRECOVERY[15] = "RECOVERY"; 
bool doCalibration = false;
volatile unsigned long buttonPressTimestamp = 0;

void(* resetFunc) (void) = 0;//declare reset function at address 

void setup() {
  Serial.begin(115200);
  bool status;

  speaker();
  
  Serial.println("Sensor CM1106 y OLED 0.96");

  Wire.begin(); //Inialize I2C Hardware
  
  if (OLED_present){
      // SSD1306_SWITCHCAPVCC = generate display voltage
      if(!display.begin(SSD1306_SWITCHCAPVCC, 0x3C)) { // Address 0x3C for 128x32
        Serial.println(F("SSD1306 allocation failed"));
        for(;;); // Don't proceed, loop forever
      }     
      // Clear the buffer
      display.clearDisplay();

      // Draw a single pixel in white
      display.drawPixel(10, 10, SSD1306_WHITE);
      display.setCursor(0,0);
      display.setTextSize(2);
      display.setTextColor(WHITE);
      display.println(VERSION_SW);

      // Show the display buffer on the screen. You MUST call display() after
      // drawing commands to make them visible on screen!
      display.display();
      delay(2000);
      Serial.println("OLED Display begin executed");    
  }

  if (CO2_sensor_present){
    mySerial.begin(BAUDRATE);                               // (Uno example) device to CM1106 serial start   
 } 

 if (OLED_present) {
    display.setTextSize(1);             // Normal 1:1 pixel scale
    display.setTextColor(SSD1306_WHITE); 
    int percentage; 
    while (millis() < PREHEATING_TIME) {
      percentage = millis()*100/PREHEATING_TIME;
      display.clearDisplay();
      if (percentage < 10) {
        display.drawBitmap(32,0,Increibles_logo,64,32,1);
      } else {
        display.setCursor(0,0);             // Start at top-left corner
        display.setTextSize(2);
        display.setTextColor(WHITE);
        display.println(F("PREHEAT..."));
        display.setCursor(60,18);             // Start at top-left corner
       
        drawPercentbar( 1, 17, SCREEN_WIDTH-10, 15,percentage, false, leyend);       
      }
      display.display();
      delay(1000);       
    }
 }
  pinMode(BUILTIN_LED, OUTPUT);
  digitalWrite(BUILTIN_LED, LOW);
  pinMode(CALIBRATION_PIN, INPUT_PULLUP);
  attachInterrupt(digitalPinToInterrupt(CALIBRATION_PIN), buttonPressISR, CHANGE);
  pinMode(verde, OUTPUT);
  pinMode(amarillo, OUTPUT);
  pinMode(rojo, OUTPUT);  
  // Apagar los led al empezar
  digitalWrite(verde, LOW);
  digitalWrite(amarillo, LOW);
  digitalWrite(rojo, LOW);
}

int ppm_uart = 0; // Variable donde vuelco el valor CO2 obtenido del CM1106

// Tipos y variables para controlar el estado del semaforo y las acciones asociadas
typedef enum {
  GREEN = 1, 
  YELLOW = 2, 
  RED = 3
} SEMAPHORE_TYPE;

SEMAPHORE_TYPE currentState = GREEN;
SEMAPHORE_TYPE lastState = RED;
const int HISTERESIS = 30;

bool showImage = false; // Variable que indicara si hay que mostrar imagen de smiley
const unsigned long NUM_CYCLES_SHOW_DATA = 10; // muestro datos lecturas durante 10 lecturas ppm
const unsigned long NUM_CYCLES_IMAGE = 2; // muestro smiley durante dos lecturas ppm en segundo plano
unsigned long cycles = 0;
const unsigned long recoveryResetTimeout = 600000;
unsigned long measureUpdatedTimeTag=0;
bool recoveryMaked=false;
bool buttonPressed = false;

void buttonPressISR() {
  if (digitalRead(CALIBRATION_PIN) == LOW) { // PRESS
    buttonPressed = true;
    buttonPressTimestamp = millis();
  } else {                                   // RELEASE
    if (buttonPressed) { // El botón se había pulsado antes
      unsigned long now;
      now = millis();
      if ( now - buttonPressTimestamp > 2000 ) {
        doCalibration = true;
      } 
      buttonPressed = false;
    }
  }
}

int cm1106_co2ppm() {
  static byte cmd[4] = {0x11, 0x01, 0x01, 0xED};
  static byte response[8] = {0};
  int ppm;

  mySerial.write(cmd, 4);
  mySerial.readBytes(response, 8);

  unsigned int responseHigh = (unsigned int) response[3];
  unsigned int responseLow = (unsigned int) response[4];

  ppm = (256 * responseHigh) + responseLow;
  Serial.print("CO2: "); Serial.print(ppm); Serial.println("ppm");

  return ppm;
}

void cm1106_clearSerial() {
    while (mySerial.available()) { mySerial.read(); };
}

byte cm1106_checksum(byte *cmd) {
    int length,
        i,
        accum = 0;
    
    // head + cmd + length + data1...datan
    length = 2 + cmd[2];

    for (i=0; i<length; i++) {
        accum += cmd[i];
    }

    return ( 256 - (accum % 256) );
}

void cm1106_calibrate(int ppm) {
    static byte cmd[6] = { 0x11, 0x03, 0x03, 0x00, 0x00, 0x00};
    static byte response[4] = {0};

    cmd[3] = ppm / 256;;
    cmd[4] = ppm % 256;
    cmd[5] = cm1106_checksum(cmd);

    cm1106_clearSerial();
    mySerial.write(cmd, 6);
    mySerial.readBytes(response, 4);    
    Serial.print("Calibrating sensor to "); Serial.print(ppm); Serial.println("ppm.");
}


void loop() {
  if (measureUpdatedTimeTag==0) measureUpdatedTimeTag = millis();
  if (CO2_sensor_present) {
    
    if (millis() - getDataTimer >= 2000) {
      getDataTimer = millis();
      int ppm_uart_read = cm1106_co2ppm()+OFFSET_CALIBRATION_PPM;
      bool newData = false;
      
      if (ppm_uart != ppm_uart_read) {
        ppm_uart = ppm_uart_read;
        measureUpdatedTimeTag=millis();
        newData = true;
      } else if (millis()-measureUpdatedTimeTag >= recoveryResetTimeout) {
        Serial.print("measureUpdatedTimeTag=");Serial.print(measureUpdatedTimeTag);Serial.print(" millis()=");Serial.println(millis());
        measureUpdatedTimeTag=millis();
        recoveryMaked = true;
      }
      
      // Una razon de newData = true tb es que pasemos a mostrar la imagen o no del smiley (pensar otra forma menos chapucera de hacerlo)
      cycles++;
      if ((!showImage) && ((cycles % NUM_CYCLES_SHOW_DATA) == 0)) {
        cycles = 0; 
        showImage = true; 
        newData = true;
      } else if ((showImage) && ((cycles % NUM_CYCLES_IMAGE) == 0)) {
        cycles = 0; 
        showImage = false;
        newData = true;
      } else if (currentState != lastState) {
        cycles = 0;
        showImage = true;
        speaker();
        lastState = currentState;
       // if (recoveryMaked == false) {
        switch (currentState) {
          case GREEN : 
            strcpy(leyend,leyendGREEN); break;
          case RED :
            strcpy(leyend,leyendRED); break;
          case YELLOW :
            strcpy(leyend,leyendYELLOW); break;
        }
       // } else {
       //   strcpy(leyend,leyendRECOVERY);
       // }
        newData = true;
      }
      

      if (newData == true) {
        p1 = ppm_uart*100/CO2_alarm_level;
         
        if (OLED_present){
          if (!showImage) {
            display.clearDisplay();
            display.setTextSize(2);
            display.setTextColor(SSD1306_WHITE); 
            display.setCursor(5,3);
            display.drawRect(1, 0, 49, 20, WHITE);
            display.drawRect(50, 0, 78, 20, WHITE);
            display.drawRect(105, 0, 23, 10, WHITE);
            display.setTextSize(1);
            display.print(F("*"));
            display.setTextSize(2);
            display.print(F("C"));
            if (ppm_uart > 1000){
              display.setCursor(55,3);            
            } else {
              display.setCursor(60,3);
            }
            display.print(ppm_uart, DEC);
            display.setTextSize(1); 
            display.setCursor(108,2);
            display.print(F("PPM")); 
            drawPercentbar( 1, 19, 127, 13,p1,true,leyend);
            display.display();
            traffic_lights(ppm_uart);
          } else { traffic_lights(ppm_uart);
          }
        }
         
      } // if (newData == true)
    } // if (millis() - getDataTimer >= 2000)  
  } // if (CO2_sensor_present)

  digitalWrite(BUILTIN_LED, buttonPressed);
  if (doCalibration) {
    doCalibration = false;
    cm1106_calibrate(CALIBRATION_VALUE);
  }

  delay(1000);
}

const int pinBuzzer = 9;

void speaker() {
  tone(pinBuzzer, 494);
  delay(50);
  tone(pinBuzzer, 392);
  delay(150);  
  tone(pinBuzzer, 694);
  delay(150);
  tone(pinBuzzer, 592);
  delay(300);
  tone(pinBuzzer, 894);
  delay(150);
  tone(pinBuzzer, 792);
  delay(300);
  noTone(pinBuzzer);  
}


void drawPercentbar(int x,int y, int width,int height, int progress, bool customLeyend, char *strCustomLeyend)
{
   int ppm = progress;
   progress = progress > 100 ? 100 : progress;
   progress = progress < 0 ? 0 :progress;

   float bar = ((float)(width-4) / 100) * progress; 

   display.drawRect(x, y, width, height, WHITE);
   display.fillRect(x+2, y+2, bar , height-4, WHITE);

   // Display progress text
   if( height >= 13){
      display.setCursor((width/2) -3, y+5 );
      display.setTextSize(1);
      display.setTextColor(WHITE);

      if( progress >=50) {
         display.setTextColor(BLACK, WHITE); // 'inverted' text
      }
      if (!customLeyend) {
        display.print(progress);
        display.print("%");      
      } else {
        switch (currentState) {
          case GREEN :
            display.setTextColor(WHITE);
            display.setCursor((width/2) +10, y+3 );
            break;
          case YELLOW :          
            display.setTextColor(BLACK, WHITE);
            display.setCursor(x+3, y+3 );
            break;
          case RED :          
            display.setTextColor(BLACK, WHITE);
            display.setCursor(x+3, y+3 );
            break;
        }
        display.print(strCustomLeyend);
      }
   }
}

void traffic_lights(int CO2_value){
      
  Serial.println(CO2_value);
  // Condicion con histeresis en bajada de estado
  if (((currentState != GREEN) && (CO2_value <= (CO2_safe_level-HISTERESIS))) ||
     ((currentState == GREEN) && (CO2_value <= CO2_safe_level))){
    // Encender el led verde y apagar el resto
    Serial.println("Parece que el aula no necesita más ventilación de momento");
    digitalWrite(verde, HIGH);
    digitalWrite(amarillo, LOW);
    digitalWrite(rojo, LOW);
    currentState = GREEN;
    if (showImage) {
      display.clearDisplay();
      display.drawBitmap(32,0,happy_icon,64,32,1);
      display.display();
    }
  } 
  // Condicion con histeresis en bajada de estado
  if (((currentState != RED) && ((CO2_value > CO2_safe_level) & (CO2_value < CO2_alarm_level))) ||
     ((currentState == RED) && ((CO2_value > CO2_safe_level) & (CO2_value < (CO2_alarm_level-HISTERESIS))))) {
    // Encender el led amarillo y apagar el resto
    Serial.println("El aire del aula necesitará renovarse pronto");
    digitalWrite(verde, LOW);
    digitalWrite(amarillo, HIGH);
    digitalWrite(rojo, LOW);
    currentState = YELLOW;
    if (showImage) {
      display.clearDisplay();
      display.drawBitmap(32,0,Surprised_icon,64,32,1);
      display.display();
    }
  }
  if (CO2_value >= CO2_alarm_level){
    // Encender el led rojo y apagar el resto
    Serial.println("Habría que ventilar el aula");
    digitalWrite(verde, LOW);
    digitalWrite(amarillo, LOW);
    digitalWrite(rojo, HIGH);
    currentState = RED;
    if (showImage) {
      display.clearDisplay();
      display.drawBitmap(32,0,Angry_icon,64,32,1);
      display.display();
    }       
  }
}

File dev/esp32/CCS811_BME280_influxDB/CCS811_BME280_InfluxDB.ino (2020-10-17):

// @Andreas_IBZ (Telegram), 17/10/2020
//
// CCS811_BME280_InfluxDB
// Medir eCO2, TVOC, presión, humedad & temperatura ambiental con ESP32, CCS811 y BME280
//
// credits to:
// https://github.com/miguelangelcasanova/codos
// https://github.com/Makespace-Mallorca/codos
// 
// ##### TODO #####

// Falta una rutina para "ponerlo a cero" - en el datasheet se llama grabar una "baseline" al sensor. 
// Esa baseline hay que leer la primera vez después del burn-in a aire fresco y luego repetirlo periódicamente - cuanto más viejo el 
// sensor, más tiempo se puede usar la misma baseline. El mismo sensor no tiene memoria non-volatil para la baseline - hay que grabar 
// la en el EEPROM del ESP y subirla al sensor cada vez que lo reiniciamos. En la librería de Sparkfun hay un ejemplo No. 4  donde pone 
// como se hace eso.
//
// Para ahorrar energía en dispositivos alimentados con batería he introducido un "modem sleep" junto a actuar el nWAKE del CCS811. Al 
// parecer el WiFi.disconnect(true); no funciona igual con cualquier ESP32. Falta por poner un retry etc. si no se puede connectar 
// después del Wake-up. 
//
// ################
//
// Descripción del código
// - Medición del ambiente mediante el BME280
// - Aplicación de la humedad y la temperatura ambiental al algorithmo del CCS811
// - Los valores eCO2, TVOC, Temperatura, Humedad y Presión 
//		 a) salen mediante serial en formato CSV prefijado por el tiempo
// 		 b) se suben al servidor configurado en InfluxDB.h (por defecto mediante HTTPS) a un "measurement" con el nombre lo que poneís en 
//			INFLUX_MEASUREMENT - para facilitar la comparación de los valores propongo usar el Telegram-Nick - ejemplo "@Andreas_IBZ",  
// 			como nombre de la base de datos propongo "CCS811EVAL" 
// - ahorrar energía: modem sleep durante el tiempo cuando no hay que mandar datos (puede que dar problemas con algunos ESP32 - para 
//	 evalorar más en detalle), CCS811 con DriveMode 3 (una medición cada minuto) y actuando el nWAKE para dormir/despertar al interfaz I²C
//
// Wiring BME280 - ESP32
// SCL - D22
// SDA - D21
// VCC - 3V3
// GND - GND
//
// Wiring CCS811 - ESP32
// VCC - 3V3
// SCL - D22
// SDA - D21
// GND - GND
// nWAKE - D5
//
// Cambios
// 17/10/2020 - cambios para pull-request @miguelangelcasanova
// 16/10/2020 - movido credenciales a InfluxDB.h y WiFi_credentials.h, añadido TODO
// 14/10/2020 - añadido setDriveMode(3) - una medición cada minuto para ahorrar energía (-20 mA => 50 mA total) y para ver si afecta a los valores; hay que dedicar tiempo a lo de la BASELINE
// 13/10/2020 - Wake up ESP32 + BME280 + CCS811 cada 3 min, resto modem sleep ( Wifi.mode (WIFI_OFF) ) => 150 mA con WiFi vs. 80 mA en modem sleep; además actuando nWAKE (-10 mA => 70 mA total)
// 12/10/2020 - release inicial
//
// ######################################################################################################################
//
#include <WiFi.h>
#include <Wire.h>
#include "time.h"
#include "InfluxArduino.hpp" // he modificado la librería para que no hace un Serial.print de la respuesta del servidor InfluxDB - el original es: https://github.com/teebr/Influx-Arduino
#include <SparkFunBME280.h> //Click here to get the library: http://librarymanager/All#SparkFun_BME280
#include <SparkFunCCS811.h> //Click here to get the library: http://librarymanager/All#SparkFun_CCS811
#include "InfluxDB.h" // credenciales y certificado del servidor influx
#include "WiFi_credentials.h" // credenciales del WiFi

// adaptar estos valores
unsigned long PERIOD = 180000; // periodo de captura en millisegundos, 180000 = 180 s = 3 min
String colsep = ";"; // separador columna de datos CSV mediante serial
bool subirAinflux = true; // poner a false si no quereís subir los datos al servidor influx
const char sensortag[] = "CCS811-001"; // cada sensor va a una serie - propongo poner un número único
int DriveMode = 3; // 0 = Idle // 1 = read every 1s // 2 = every 10s // 3 = every 60s // 4 = RAW mode, no algorithms

// Definiciones CCS811
//#define CCS811_ADDR 0x5B // Default CCS811 I2C Address
#define CCS811_ADDR 0x5A // Alternate CCS811 I2C Address
#define PIN_NOT_WAKE 5 // nWAKE Pin en D5

// NTP-Server
const char* ntpServer = "pool.ntp.org";
const long  gmtOffset_sec = 3600; // GMT+1 timezone
const int   daylightOffset_sec = 3600; // summer time +1h
char meastime[32];

// Global objects
CCS811 myCCS811(CCS811_ADDR);
BME280 myBME280;
InfluxArduino influx;

long val_eCO2 = 0; // valor eCO2
long val_TVOC = 0; // valor TVOC
float BMEtempC = 0.0; // valor Temperatura
float BMEhumid = 0.0; // valor Humedad
float BMEpres = 0.0; // valor Presión

void setup()
{   pinMode(PIN_NOT_WAKE, OUTPUT);
    delay(100);
    digitalWrite(PIN_NOT_WAKE, LOW); // despertar CCS811
    delay(100);
    Serial.begin(115200);
    WiFi.begin(WIFI_NAME, WIFI_PASS);
    while (WiFi.status() != WL_CONNECTED) {
        delay(500);
        Serial.print(".");
   }
    Serial.println("WiFi connected!");
    delay(500);
    
    // Empezar comunicación I2C
    Wire.begin();
    // This begins the CCS811 sensor and prints error status of .beginWithStatus()
    CCS811Core::CCS811_Status_e returnCode = myCCS811.beginWithStatus();
    Serial.print("CCS811 begin exited with: ");
    Serial.println(myCCS811.statusString(returnCode));
    myCCS811.setDriveMode(DriveMode); 
    
    if (subirAinflux) {  // solo si queremos subir datos a influxDB
    influx.configure(INFLUX_DATABASE,INFLUX_IP); // third argument (port number) defaults to 8086
    influx.authorize(INFLUX_USER,INFLUX_PASS); // comment out if you don't have set the Influxdb .conf variable auth-enabled to true
    influx.addCertificate(ROOT_CERT); // comment if you don't have generated a CA cert and copied it into InfluxDB.h
    Serial.print("Using influx with HTTPS: ");
    Serial.println(influx.isSecure()); // will be true if you've added a ROOT_CERT to the InfluxDB.h file.
    delay(1000);
    }

    // Setup servidor de tiempo NTP
    configTime(gmtOffset_sec, daylightOffset_sec, ntpServer);
	
	// cabezal del archivo CSV
    Serial.print("Start of measurement: ");
    printLocalTime();
    Serial.println();
    Serial.print("Measurement by: ");
    Serial.println(INFLUX_MEASUREMENT);
    Serial.print("Sensor: ");
    Serial.println(sensortag);


  //For I2C, enable the following and disable the SPI section
  myBME280.settings.commInterface = I2C_MODE;
  myBME280.settings.I2CAddress = 0x76;

  //Initialize BME280
  //For I2C, enable the following and disable the SPI section
  myBME280.settings.commInterface = I2C_MODE;
  myBME280.settings.I2CAddress = 0x76;
  myBME280.settings.runMode = 3; //Normal mode
  myBME280.settings.tStandby = 0;
  myBME280.settings.filter = 4;
  myBME280.settings.tempOverSample = 5;
  myBME280.settings.pressOverSample = 5;
  myBME280.settings.humidOverSample = 5;
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

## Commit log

2020-08-29 Update README.md with Arduino version
2020-08-30 Add serial-plotter sample
2020-09-12 STL v0.3 zipped to save space
2020-09-19 Añadida caja
    [cajaco2_codos.stl, tapacajaCOdos.stl]
2020-09-20 Codos version Arduino nano - Sin soporte Wifi (sin servidor web) - Con OLED 1306 (128x32) - Incluye carga de imagenes bmp y llamadas graficas con Adafruit_SSD1306.h - Lectura por SWSERIAL del sensor 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
2020-09-23 correction base TTGO T1, added premarked holes for LEDs
2020-09-27 Par Wemos D1 mini con MQTT
    Versión basada en Wemos D1 mini con comunicación MQTT bidirección.
    [codos_WeMos_D1_Mini_Pro_esquemático.fzz]
2020-10-02 Añadidos tonos en los cambios de estado con zumbador por PWM en la D9
2020-10-03 added case & base for UNO, reduced wall thickness
2020-10-04 Modificados cambios de estado para añadir Histeresis en la bajada y reducir el numero de tonos cuando se producen las transiciones
2020-10-06 Añado la version de sw al inicio de la ejecucion.
2020-10-11 Fix Typos In Sensor Name
2020-10-17 añadido versión ESP32, CCS811, BME280 & influxDB
2020-10-17 update README and reorganize version folders
    [codos_WeMos_D1_Mini_Pro_esquemático.fzz]
2020-10-17 Añadida la guís de programación del CCS811
2020-10-25 En esta version elimino la autocalibracion.
2020-10-25 Primera version colegio. Eliminada calibracion de -100ppm Subidos limites amarillo y rojo
2020-10-31 MH-Z19B
    Usando el sensor MH-Z19B que me indica la temperatura y el nivel de CO2.
2020-11-07 Add files via upload
    Datasheed del ultimo modelo de MH-Z19B, ver. 1.5
2020-11-08 Version que hace que el sensor funcione peor y se trabe todo el rato
2020-11-23 Version 1.10 Añadido sistema de recuperacion ante congelamiento del sensor (watchdog reset a los 10 mins) Gestion de zumbador
    [codosnanoMHZ19B.ino]
2020-12-01 se recomienda el MH-Z19 antes que el CCS811
2021-01-16 Modificaciones en las rutas para adaptarse a Platformio
2021-01-18 arduino nano + oled + CM1106 sensor
